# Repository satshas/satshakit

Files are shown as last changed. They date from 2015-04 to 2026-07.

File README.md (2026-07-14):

**IMPORTANT:** this repository is outdated, please find all the new repos about the satshakit boards here: **[satshakit Github organization](https://github.com/satshakit/)**

<h1 style="font-family: courier;" align="center"> satshakit</h1>
<p align="center">
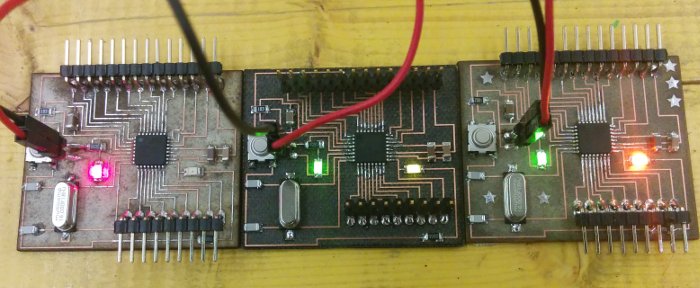
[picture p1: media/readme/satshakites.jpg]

<div align="center"><i>An improved & fabbable 100% Arduino IDE/libraries compatible board.</i></div>
</p>  

The story
--
satshakit born during my **[FabAcademy2015](http://fabacademy.org/archives/2015/eu/students/ingrassia.daniele/index.html)**  as one the first test boards for my quadcopter final project. As some of my fellow students had difficulties with **[Fabkit](http://fabacademy.org/archives/2015/doc/projects/fabkit-0.4.html)**, they tried to make this prototype board. The board was very appreciated that now almost all my fellow students made it for their exercises, or use it as a **starting point for their final projects**. Thus I decided to do this release, if anyone wants to try it. Now, one year later, I am again in a FabLab developing new satshakit boards in my spare time.

What is satshakit?
--

satshakit is a **100% Arduino IDE  and libraries compatible**, fabbable and open source board, and also an improved version of [Fabkit](http://fabacademy.org/archives/2015/doc/projects/fabkit-0.4.html). 

Main **improvements and features** over Fabkit are:

- **16Mhz** instead of 8Mhz
- **crystal** instead of resonator
- **costs less** (7-9 euro vs 13 euro)
- 100% compatible with **default Arduino IDE** (satshakit is recognized as Arduino UNO)
- ADC6/7 connected instead of ADC6/7 not connected (satshakit laser and cnc)
- larger space to easy soldering (satshakit laser and cnc)

satshakit boards
--

There are different kinds of **satshakit boards** depending on the **fabrication technique** you will use to make them, or on the **size** of the board. 

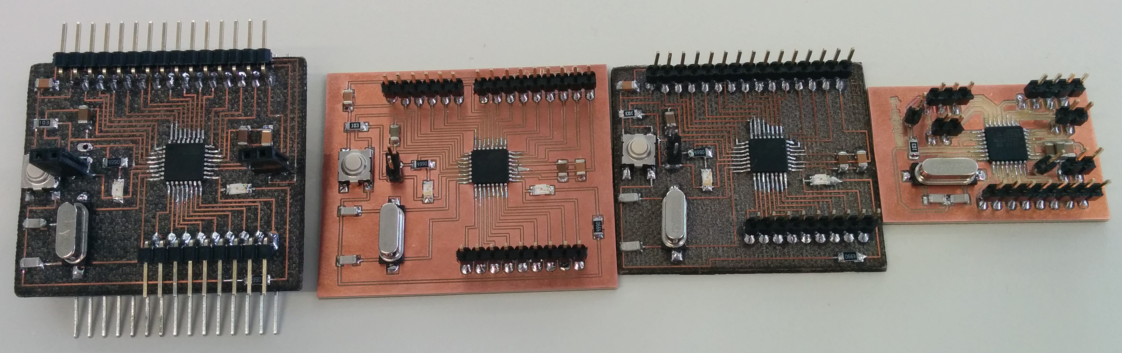
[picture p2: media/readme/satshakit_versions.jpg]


Here is a comparison table about different satshakit boards:

|name|mcu|pins|size(mm)|
| :---: | :---:|:---:|:---:|
|`satshakit laser`|ATmega328P|Arduino + ADC6/7|48 x 42|
|`satshakit cnc`|ATmega328P| Arduino + ADC6/7  |54 x 45|
|`satshakit multicore`|2 x ATmega328P| 2 x Arduino + ADC6/7|50 x 42|
|`satshakit micro`| ATmega328P|Arduino|40 x 24|

satshakit laser and cnc
--

**satshakit laser** and **satshakit cnc** are the standard versions of the satshakit. They are actually the same board, showing some layout differences to improve the fabrication process using a **fiber laser** cutter machine, or a little **cnc mill**. These satshakits are meant to be a general purpose board, having the full Arduino pinout plus ADC6/7 pins, large space for easy soldering and two led onboard for power and pin 13.

Here is the **satshakit laser board**:

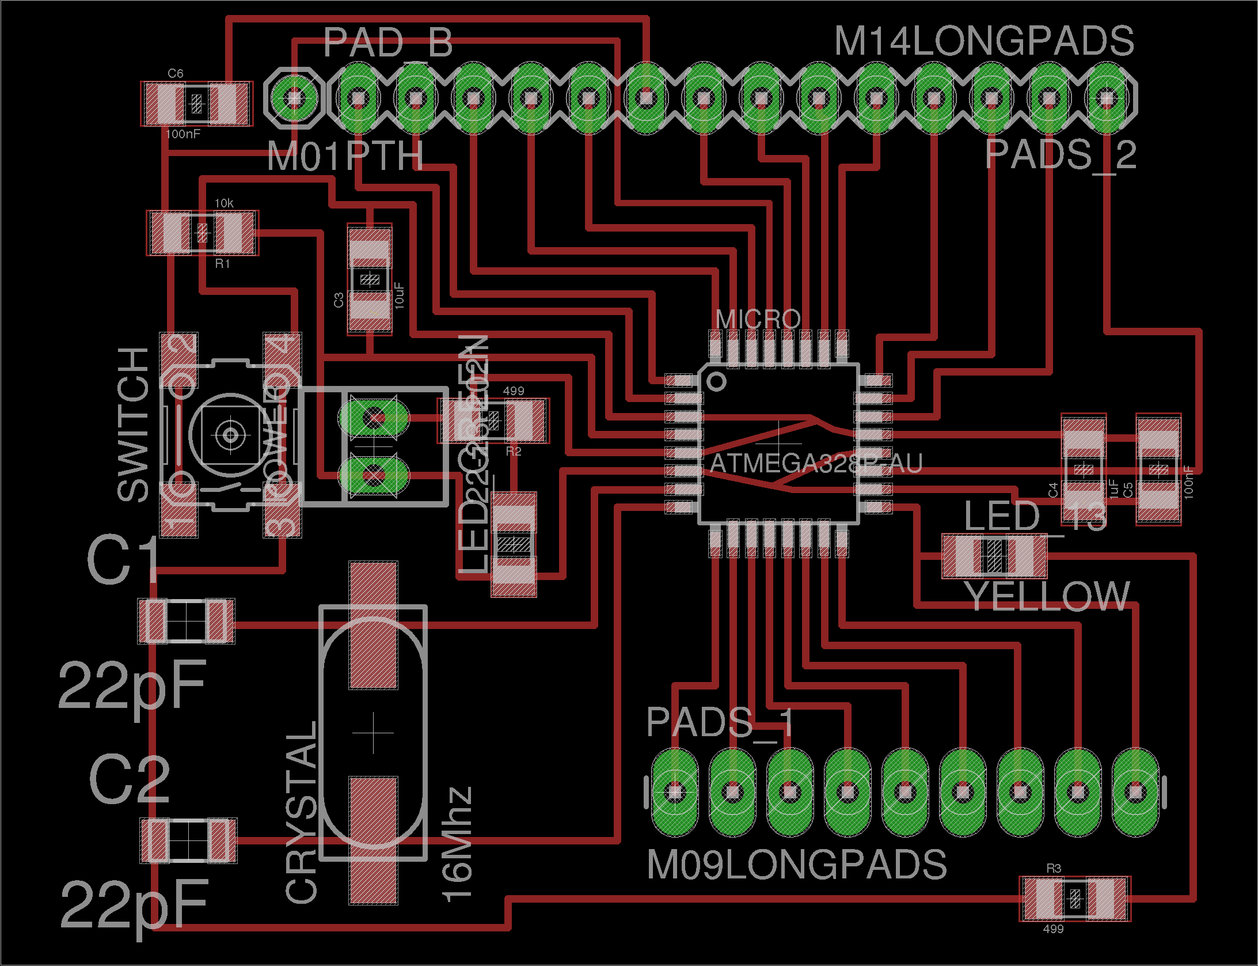
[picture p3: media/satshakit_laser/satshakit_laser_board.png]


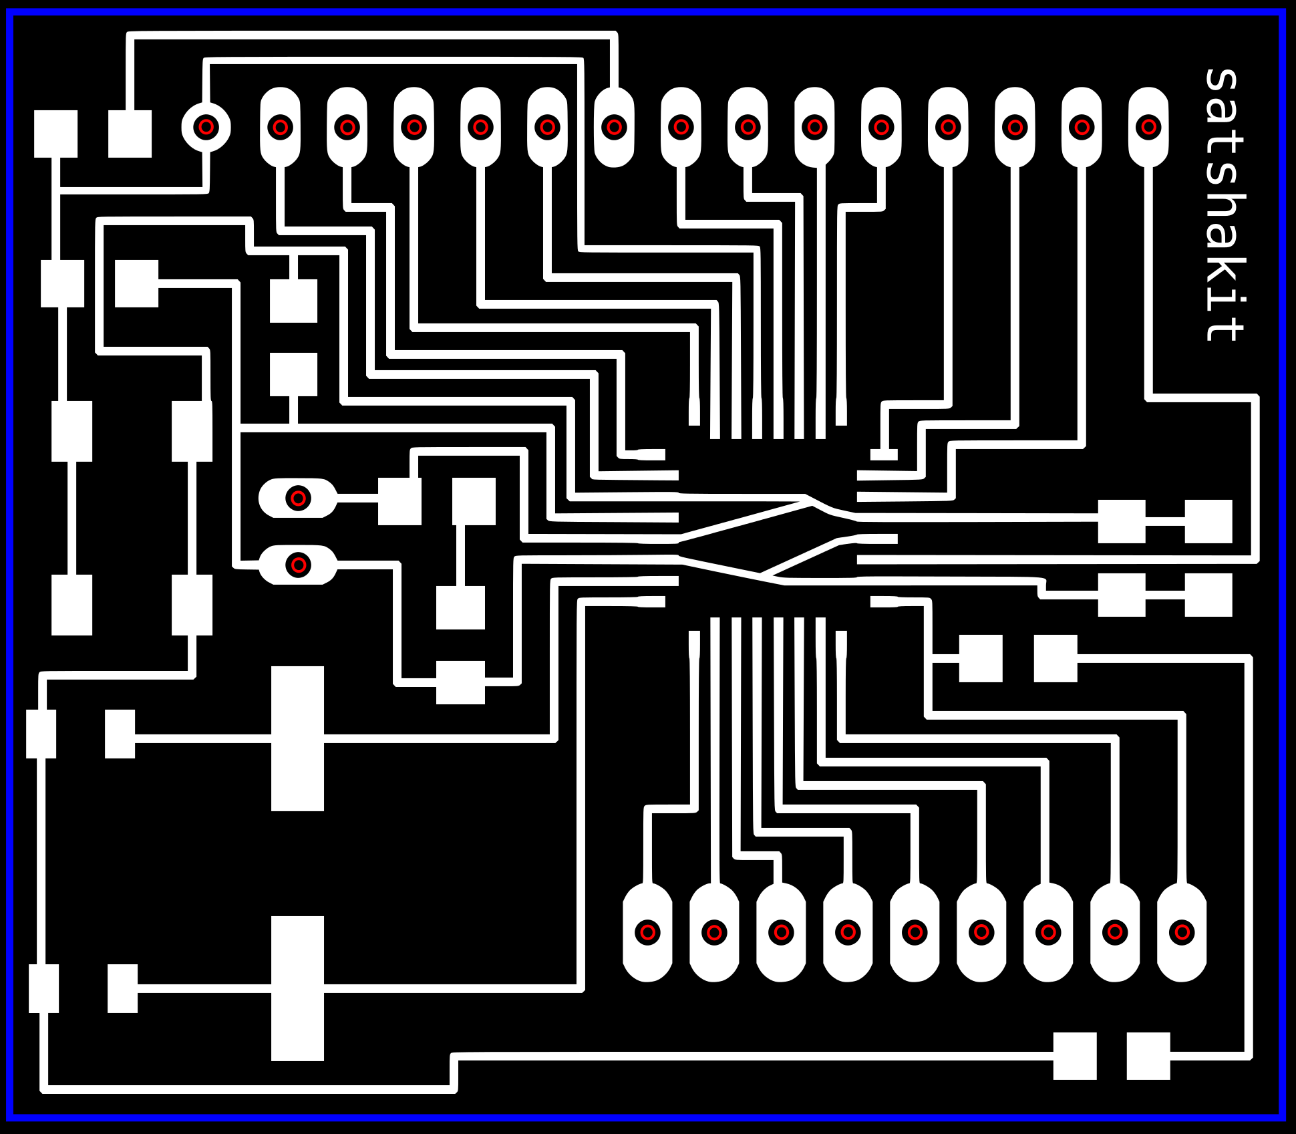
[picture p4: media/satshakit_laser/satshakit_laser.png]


And this is the **satshakit cnc board**:

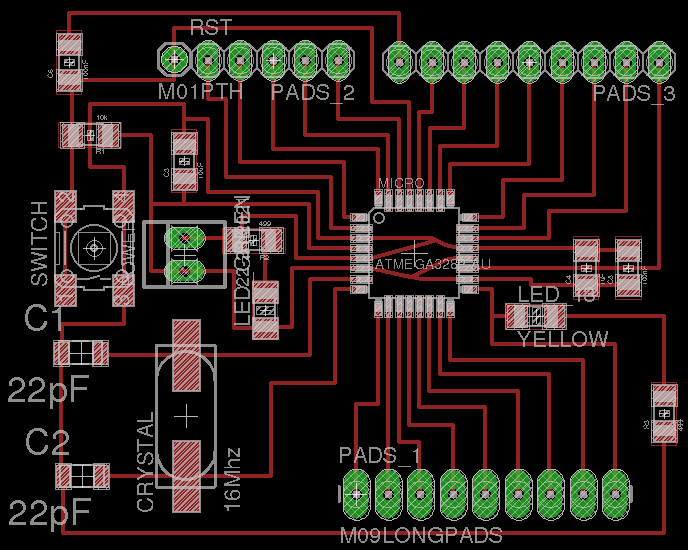
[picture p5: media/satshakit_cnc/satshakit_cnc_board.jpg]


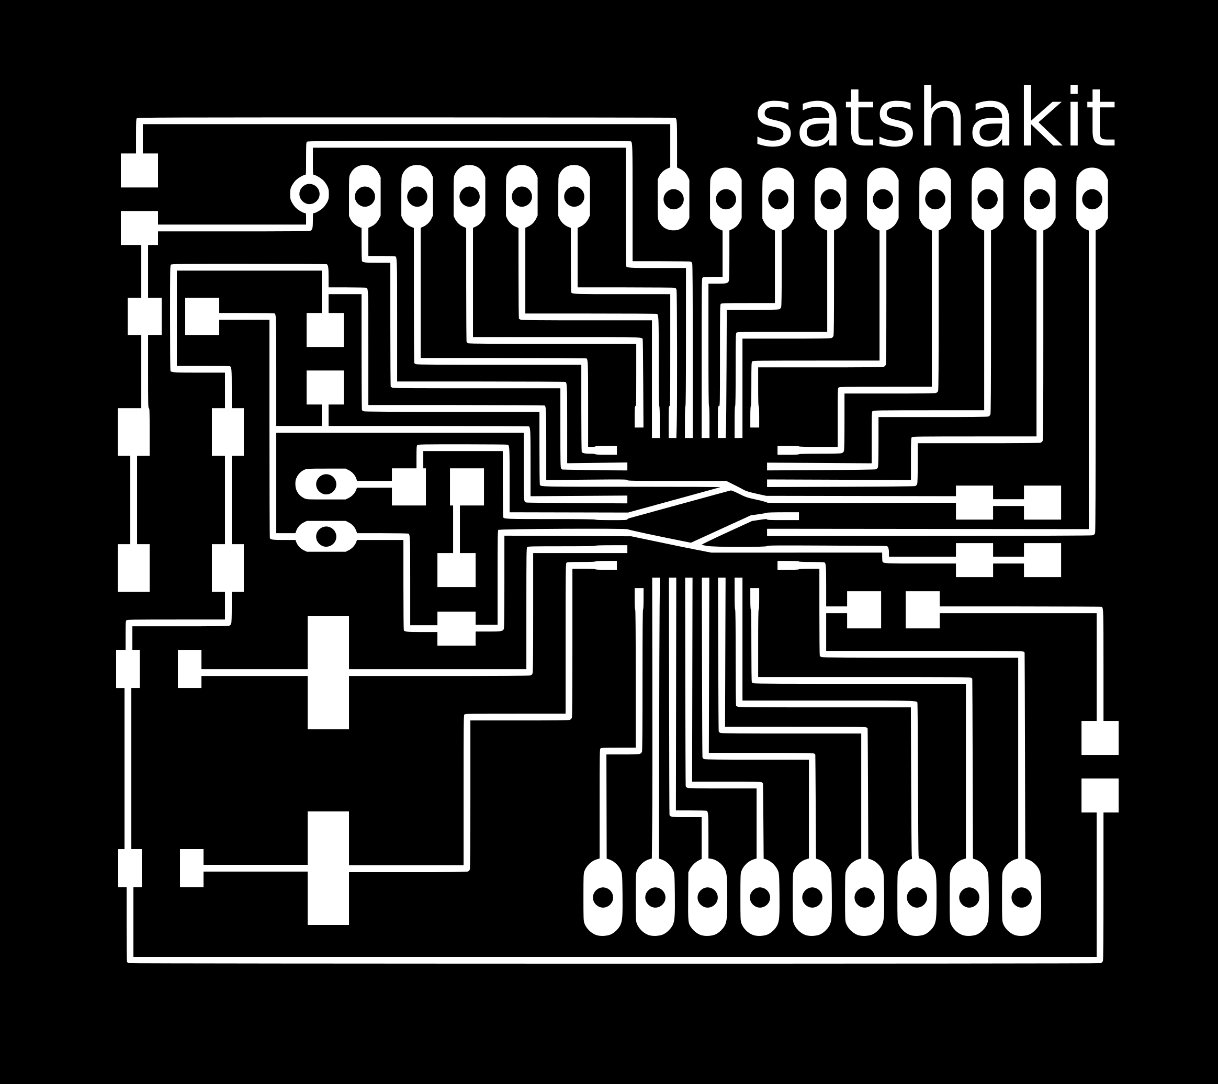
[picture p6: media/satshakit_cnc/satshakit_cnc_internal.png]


**downloads (right click, download as)**

- [satshakit cnc svg](https://raw.githubusercontent.com/satshas/satshakit/master/media/satshakit_cnc/satshakit_cnc.svg)
- [satshakit cnc internal png](https://raw.githubusercontent.com/satshas/satshakit/master/media/satshakit_cnc/satshakit_cnc_internal.png)
- [satshakit cnc holes png](https://raw.githubusercontent.com/satshas/satshakit/master/media/satshakit_cnc/satshakit_cnc_holes.png)
- [satshakit cnc cut png](https://raw.githubusercontent.com/satshas/satshakit/master/media/satshakit_cnc/satshakit_cnc_cut.png)
- [satshakit cnc cut tips png](https://raw.githubusercontent.com/satshas/satshakit/master/media/satshakit_cnc/satshakit_cnc_cut_tip.png)
- [satshakit cnc schematic](https://raw.githubusercontent.com/satshas/satshakit/master/eagle_projects/satshakit_cnc/satshakit_cnc.sch)
- [satshakit cnc board](https://raw.githubusercontent.com/satshas/satshakit/master/eagle_projects/satshakit_cnc/satshakit_cnc.brd)
- [satshakit laser svg](https://raw.githubusercontent.com/satshas/satshakit/master/media/satshakit_laser/satshakit_laser.svg)
- [satshakit laser schematic](https://raw.githubusercontent.com/satshas/satshakit/master/eagle_projects/satshakit_laser/satshakit_laser.sch)
- [satshakit laser board](https://raw.githubusercontent.com/satshas/satshakit/master/eagle_projects/satshakit_laser/satshakit_laser.brd)
- [satshakit laser and cnc BOM Open Document](https://github.com/satshas/satshakit/raw/master/docs/satshakit_others/satshakit_BOM.ods)
- [satshakit laser and cnc BOM Excel](https://github.com/satshas/satshakit/raw/master/docs/satshakit_others/satshakit_BOM.xlsx)

**media**

satshakit laser:

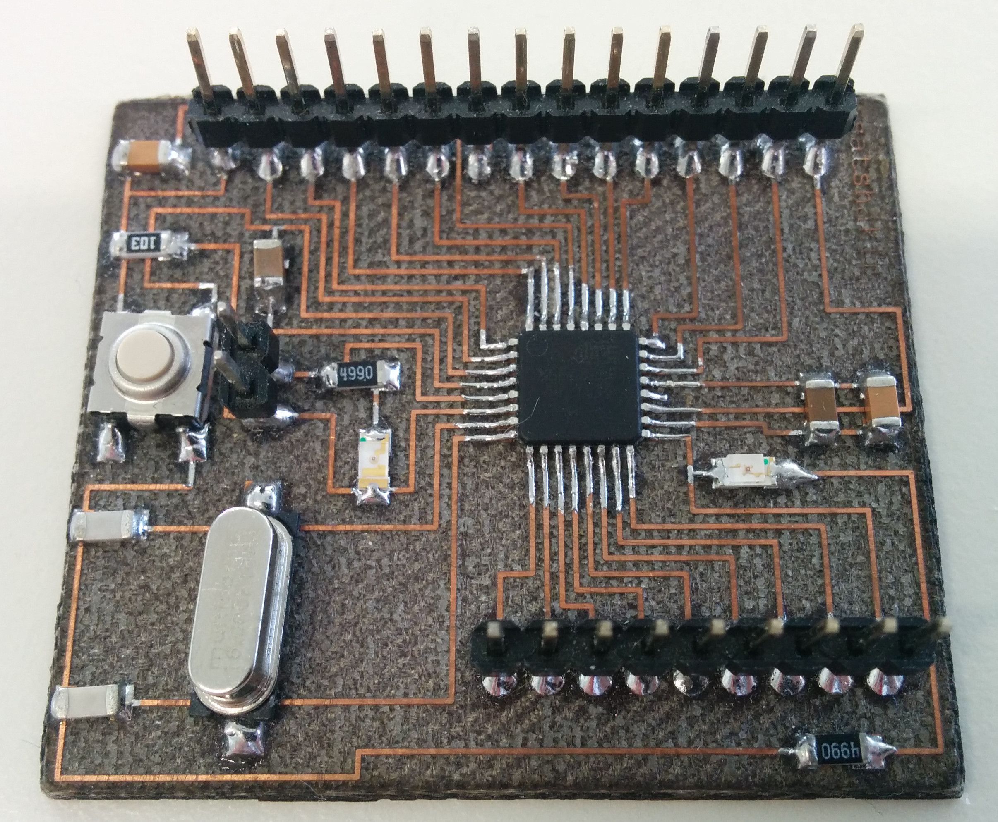
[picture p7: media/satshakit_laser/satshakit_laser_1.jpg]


satshakit cnc:

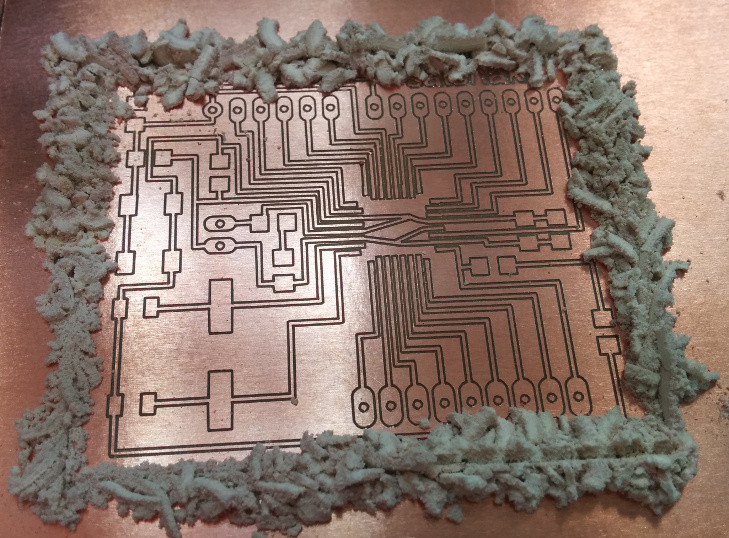
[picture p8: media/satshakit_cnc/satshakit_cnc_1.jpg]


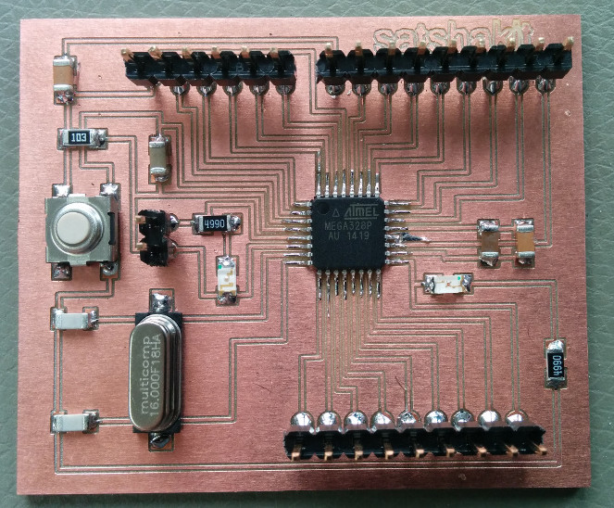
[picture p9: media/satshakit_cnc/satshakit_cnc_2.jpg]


satshakit cnc blinks:

<a href="http://www.youtube.com/watch?feature=player_embedded&v=38LhM9Qynuc
" target="_blank"></a>

satshakit programmed with a FabISP:

<a href="http://www.youtube.com/watch?feature=player_embedded&v=YNITEv0ebkc
" target="_blank"></a>

Here are some videos of satshakit while is working with **different configuration and/or sensors**:

<a href="http://www.youtube.com/watch?feature=player_embedded&v=Gk_RFebLofY
" target="_blank"></a>

<a href="http://www.youtube.com/watch?feature=player_embedded&v=ZQmN3uTlZuc
" target="_blank"></a>

<a href="http://www.youtube.com/watch?feature=player_embedded&v=kZMLoyP47z4
" target="_blank"></a>

<a href="http://www.youtube.com/watch?feature=player_embedded&v=9XcrL3Ypu_s
" target="_blank"></a>

<a href="http://www.youtube.com/watch?feature=player_embedded&v=zIuTUFps1bE
" target="_blank"></a>

satshakit car with sonars sensors and Raspberry Pi:

<a href="http://www.youtube.com/watch?feature=player_embedded&v=A0I6Nj6D2sE
" target="_blank"></a>

satshakit little radar, a **satshakit modified board** with an ULN2003A:

<a href="http://www.youtube.com/watch?feature=player_embedded&v=0FD7bHNqlxU
" target="_blank"></a>

satshakit micro
--

**satshakit micro** is a downsized version of the satshakit laser and cnc, developed to be used in **constrained space applications** like embedding the board in textiles or in small objects, or useful for who wants just a **bare metal board** to start with, also easy to be modified and/or customized. While satshakit micro is less than half the size of the other satshakits, it's a **full featured board** with the full Adruino pinout, missing only the possibility to be programmed using an FTDI cable.

Here is the **satshakit micro board**:

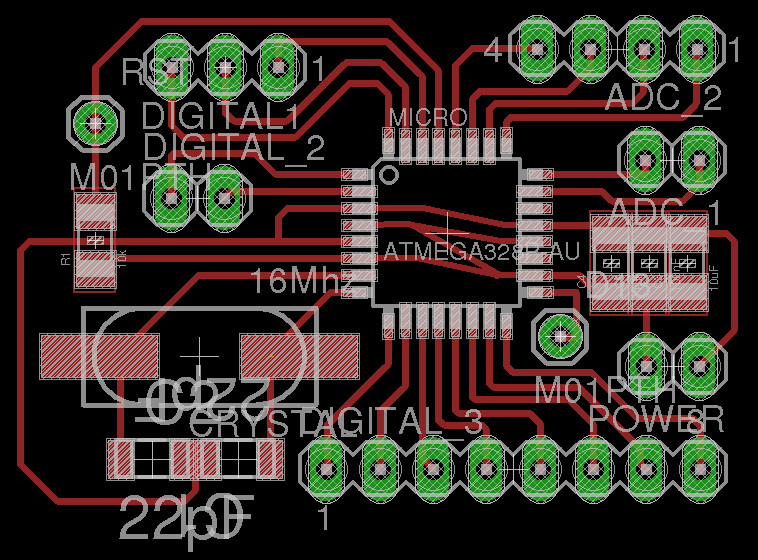
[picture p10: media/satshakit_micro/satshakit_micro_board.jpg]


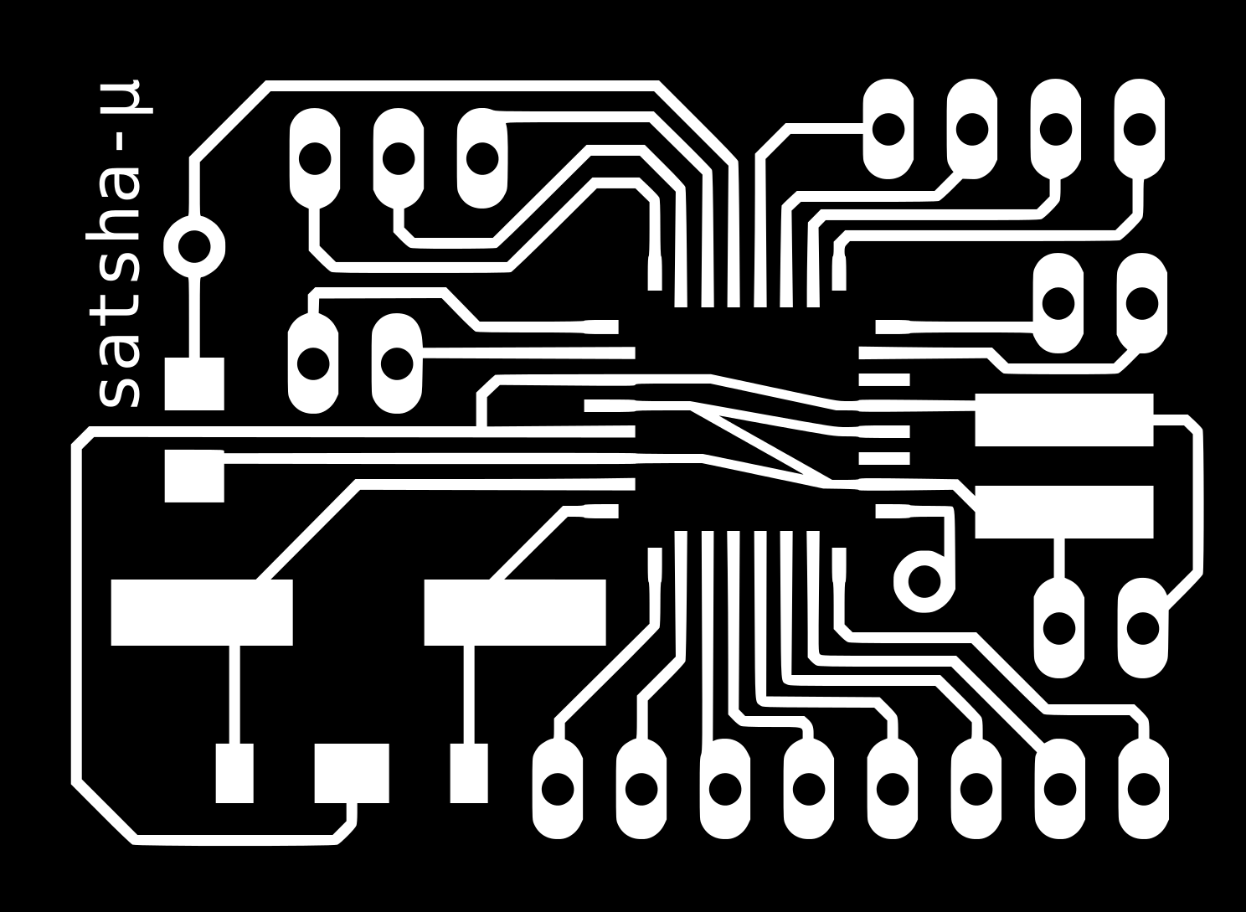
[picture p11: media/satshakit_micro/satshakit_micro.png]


**downloads (right click, download as)**

- [satshakit micro svg](https://raw.githubusercontent.com/satshas/satshakit/master/media/satshakit_micro/satshakit_micro.svg)
- [satshakit micro internal png](https://raw.githubusercontent.com/satshas/satshakit/master/media/satshakit_micro/satshakit_micro_internal.png)
- [satshakit micro holes png](https://raw.githubusercontent.com/satshas/satshakit/master/media/satshakit_micro/satshakit_micro_holes.png)
- [satshakit micro cut png](https://raw.githubusercontent.com/satshas/satshakit/master/media/satshakit_micro/satshakit_micro_cut.png)
- [satshakit micro cut tips png](https://raw.githubusercontent.com/satshas/satshakit/master/media/satshakit_micro/satshakit_micro_cut_tips.png)
- [satshakit micro schematic](https://raw.githubusercontent.com/satshas/satshakit/master/eagle_projects/satshakit_micro/satshakit_micro.sch)
- [satshakit micro board](https://raw.githubusercontent.com/satshas/satshakit/master/eagle_projects/satshakit_micro/satshakit_micro.brd)
- [satshakit micro BOM Open Document](https://github.com/satshas/satshakit/raw/master/docs/satshakit_micro/satshakit_micro_BOM.ods)
- [satshakit micro BOM Excel](https://github.com/satshas/satshakit/raw/master/docs/satshakit_micro/satshakit_micro_BOM.xlsx)

**media**

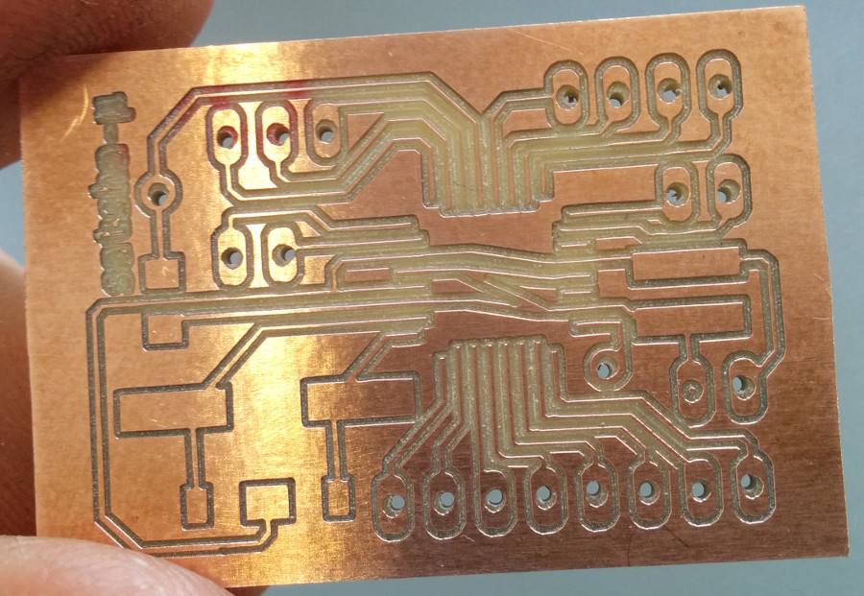
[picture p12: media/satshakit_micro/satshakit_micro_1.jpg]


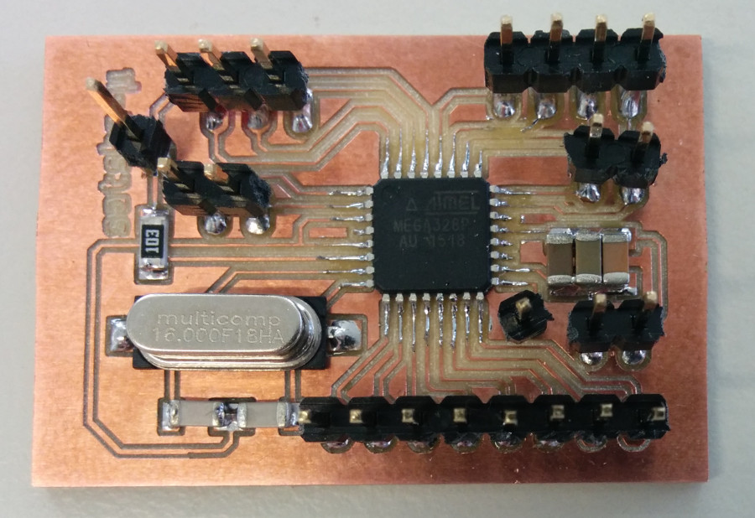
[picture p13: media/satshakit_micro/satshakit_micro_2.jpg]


satshakit micro blink:

<a href="http://www.youtube.com/watch?feature=player_embedded&v=3qz0hKS8dOc
" target="_blank"></a>

satshakit multicore
--

**satshakit multicore** boards born as a further experiment on **MCU multithreading and networking**. satshakit multicore boards have only the following modifications in confront of the standard satshakit: 4 extra pin headers (1 GND,1 VCC,1 A4, 1 A5). These pin headers serve also a structural pillars to build a modular satshakit tower. So modular satshakit share the same power source, and can direct communicate with **I2C**. 

Here is the **satshakit multicore board**:

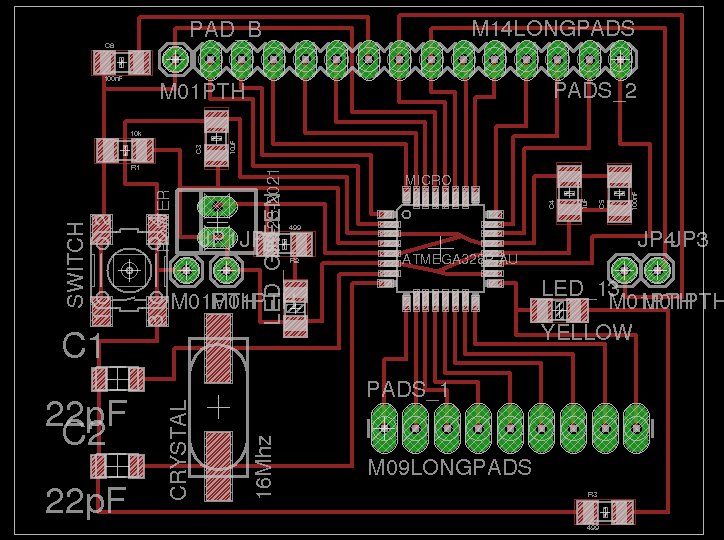
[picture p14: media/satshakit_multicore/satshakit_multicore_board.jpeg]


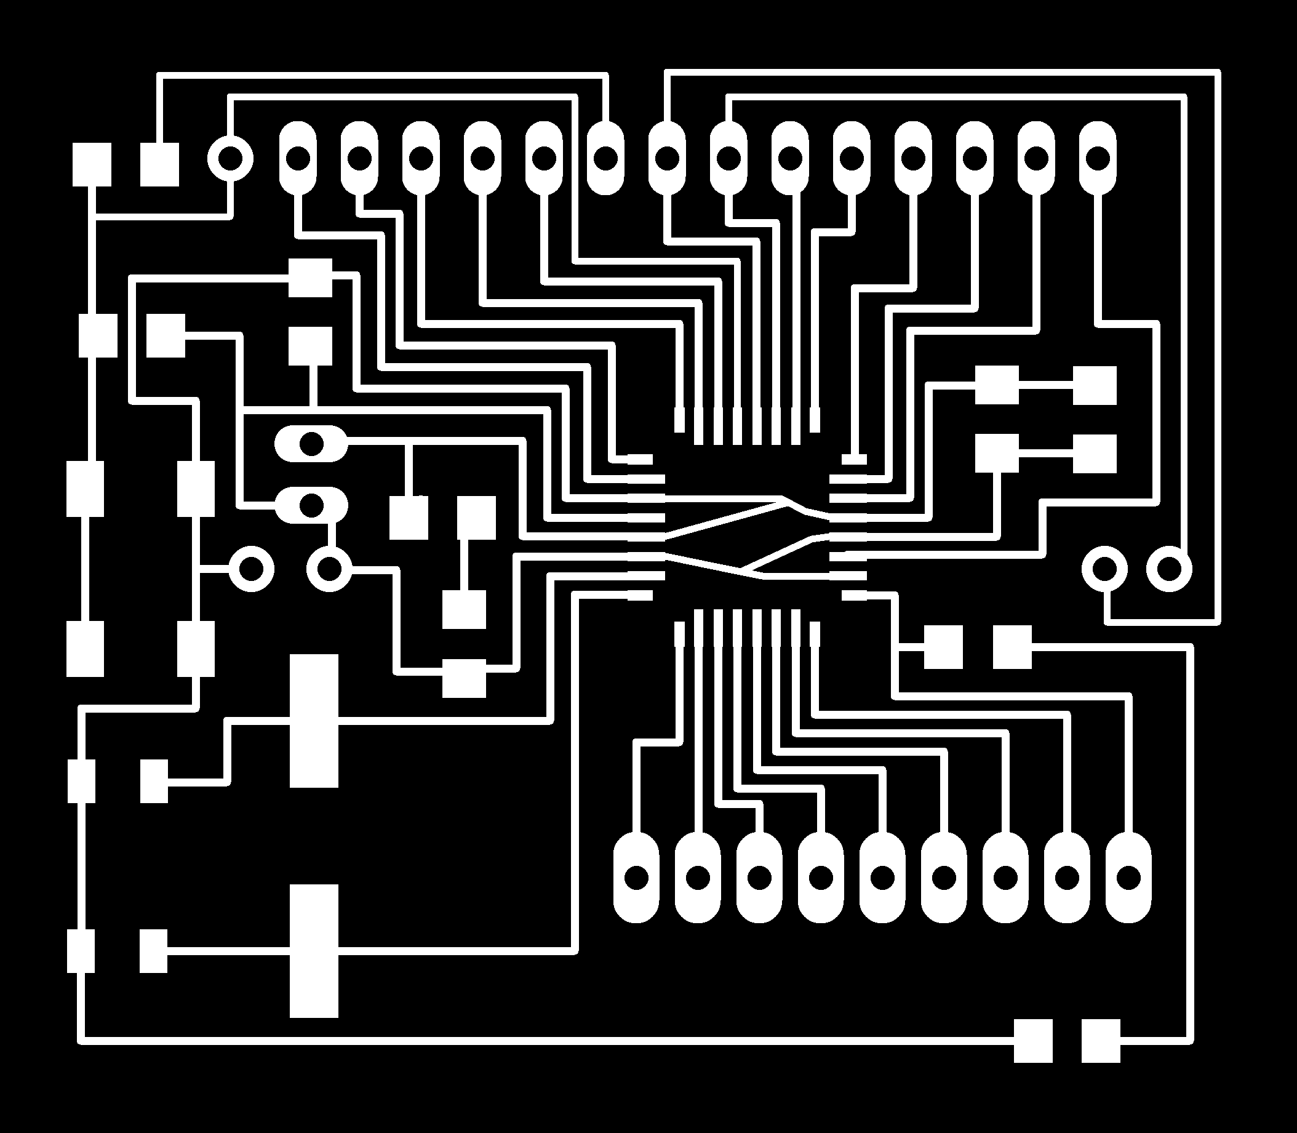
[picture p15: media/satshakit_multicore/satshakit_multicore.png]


**downloads (right click, download as)**

- [satshakit multicore svg](https://raw.githubusercontent.com/satshas/satshakit/master/media/satshakit_multicore/satshakit_multicore.svg)
- [satshakit multicore schematic](https://raw.githubusercontent.com/satshas/satshakit/master/eagle_projects/satshakit_multicore/satshakit_multicore.sch)
- [satshakit multicore board](https://raw.githubusercontent.com/satshas/satshakit/master/eagle_projects/satshakit_multicore/satshakit_multicore.brd)
- [satshakit multicore BOM Open Document](https://github.com/satshas/satshakit/raw/master/docs/satshakit_others/satshakit_BOM.ods)
- [satshakit multicore BOM Excel](https://github.com/satshas/satshakit/raw/master/docs/satshakit_others/satshakit_BOM.xlsx)

**media**

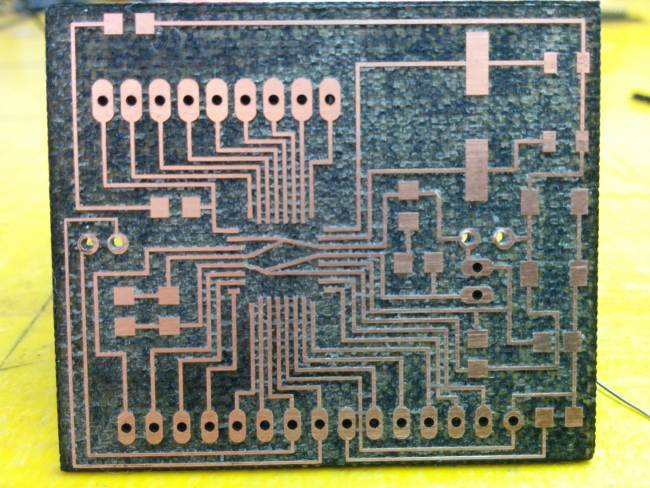
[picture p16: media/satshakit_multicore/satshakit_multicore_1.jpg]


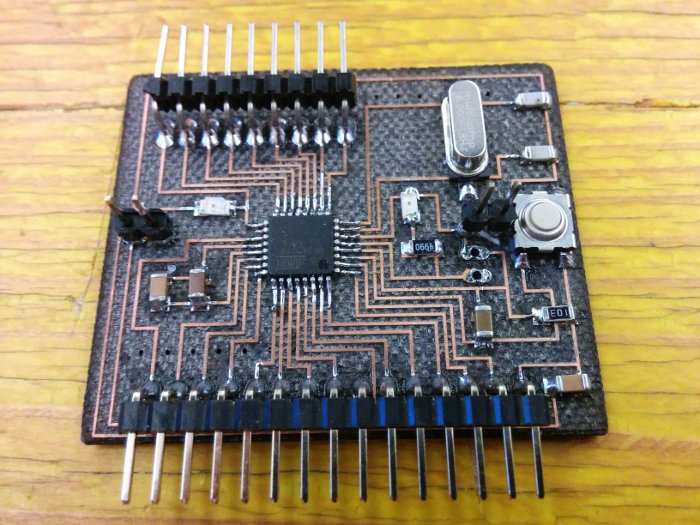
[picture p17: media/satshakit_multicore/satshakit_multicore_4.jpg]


5-core satshakit system:

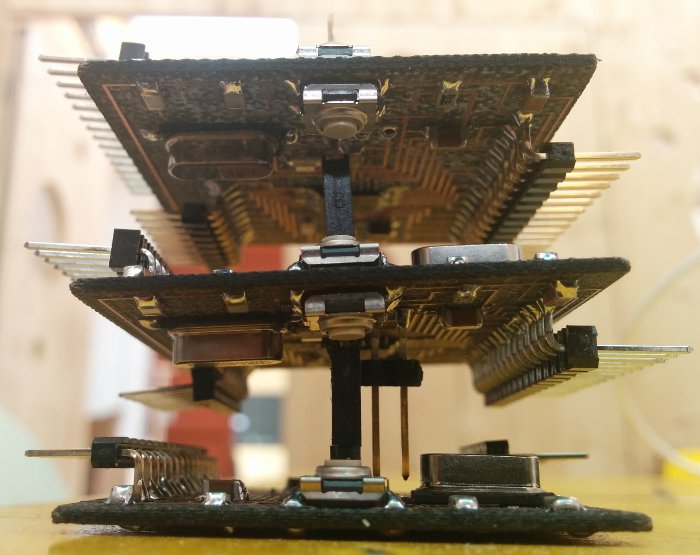
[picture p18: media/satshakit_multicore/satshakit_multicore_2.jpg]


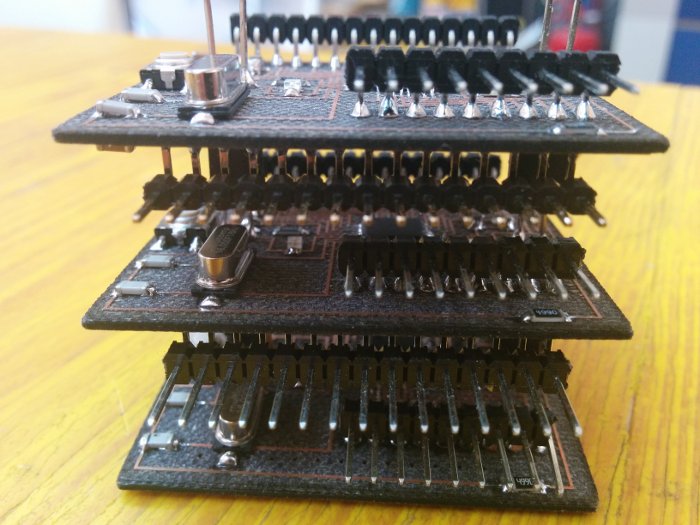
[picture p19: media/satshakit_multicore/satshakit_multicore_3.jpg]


satshakit multicore assembly & test:

<a href="http://www.youtube.com/watch?feature=player_embedded&v=nVHYBydPKpk
" target="_blank"></a>

satshakit multicore blink:

<a href="http://www.youtube.com/watch?feature=player_embedded&v=bxnmX-B9Czo
" target="_blank"></a>

quad satshakit bluetooth triangulation:

<a href="http://www.youtube.com/watch?feature=player_embedded&v=uuVuoD9TB4M
" target="_blank"></a>

satshakit power board
--

Due to the power requirements of a multicore satshakit system and to eventually provide power to **3.3V devices**, I have also developed a simple power board. This power board can work with 7V-12V as input voltage, and give out 5V and 3.3V. I made this power board with the components I had available, obviously you can make this board only with SMD components.

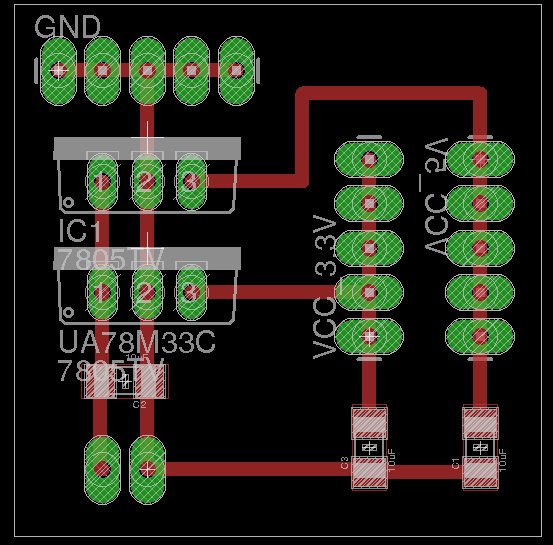
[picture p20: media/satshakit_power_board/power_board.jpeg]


**downloads (right click, download as)**

- [satshakit power board schematic](https://raw.githubusercontent.com/satshas/satshakit/master/eagle_projects/satshakit_power_board/satshakit_power_board.sch)
- [satshakit power board board](https://raw.githubusercontent.com/satshas/satshakit/master/eagle_projects/satshakit_power_board/satshakit_power_board.brd)

Here is a picture of a soldered power board:

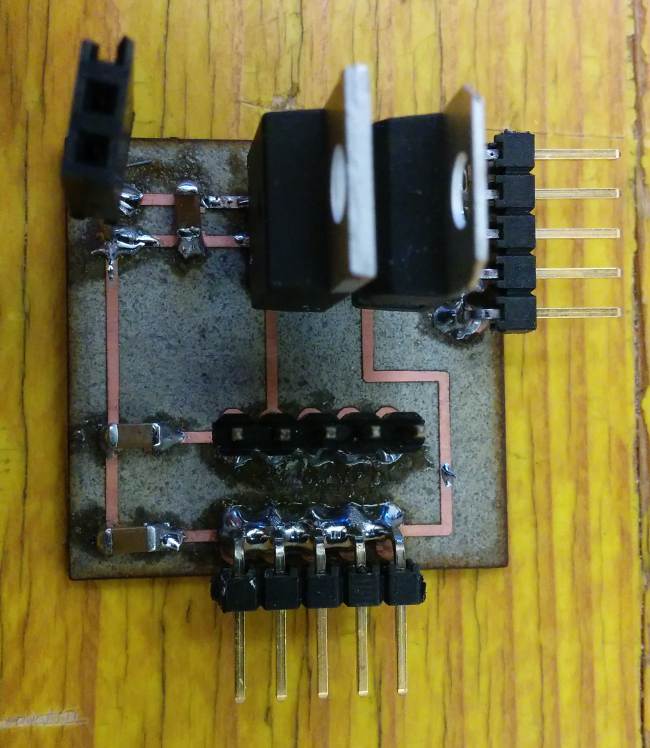
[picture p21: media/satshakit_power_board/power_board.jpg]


Getting Started
--
A satshakit board is **totally like an Arduino board**, thus is possible to use the Arduino IDE without any modification. When you finish solder satshakit, you're ready to program it. If you want to use satshakit as an Arduino, you first need to **upload Arduino bootloader**. This will also set the ATmega328P fuses as the same of an Arduino UNO.
 To do this you need to use a **programmer**, for example another Arduino or FabISP. If you plan to program a satshakit with an Arduino, be sure to upload the **Arduino as ISP skecth** before connecting the satshakit to it.

Here are the connection schemas to program **satshakit laser**, **satshakit cnc** or a **satshakit multicore** with an Arduino as ISP or with a FabISP:

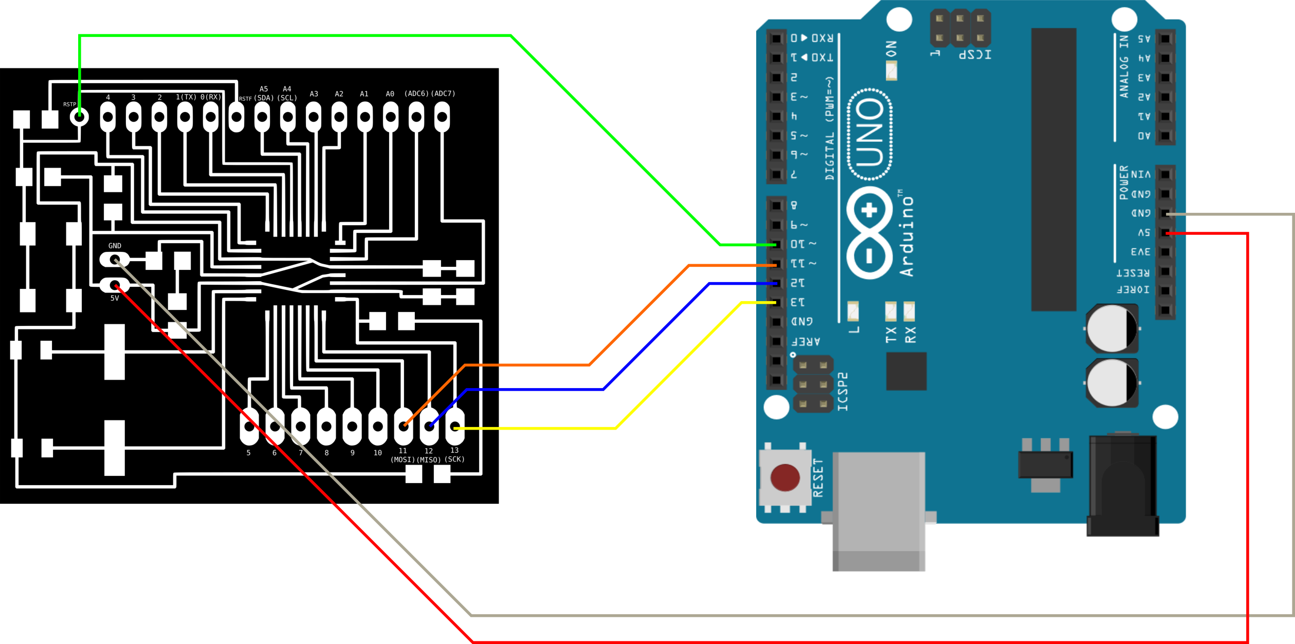
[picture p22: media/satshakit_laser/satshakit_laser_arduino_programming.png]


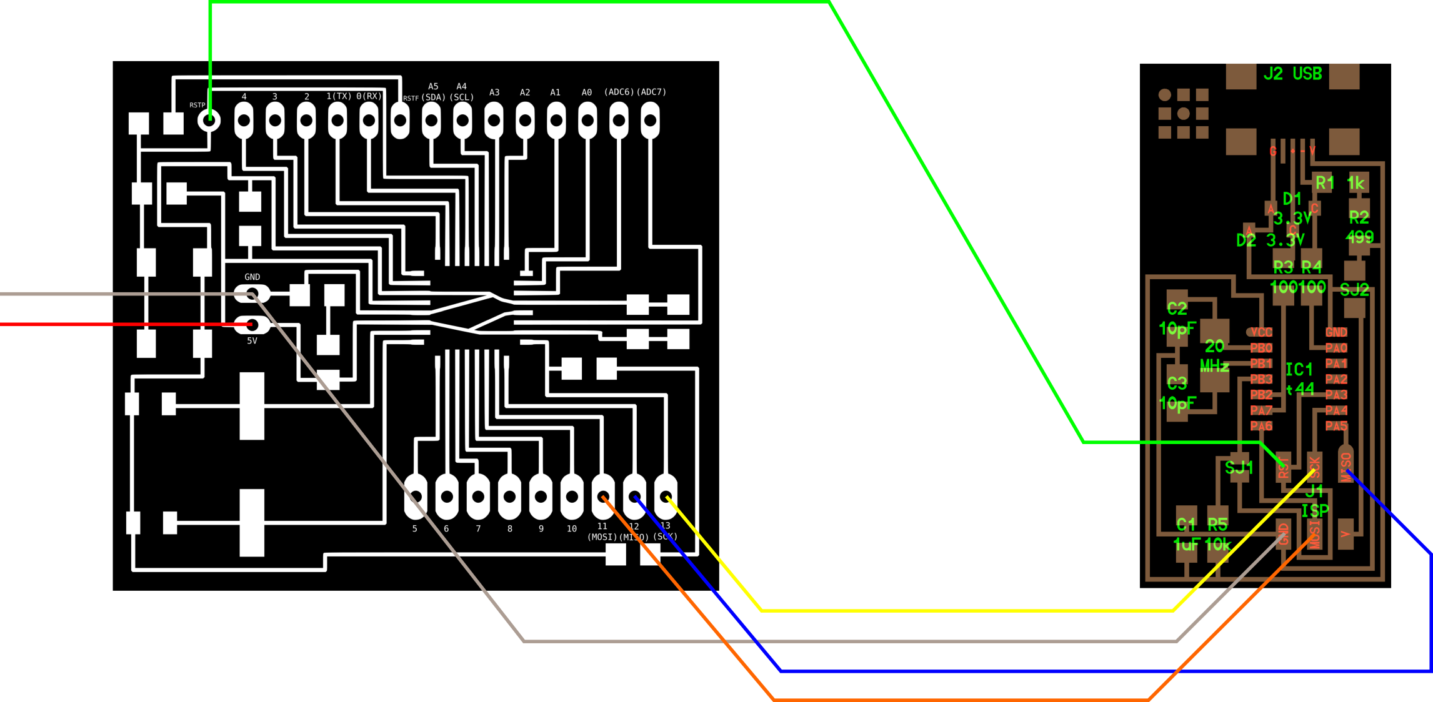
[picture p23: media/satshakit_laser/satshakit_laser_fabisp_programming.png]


If you made a **satshakit micro**, here are the connection schemas to program it as before for the other satshakits:

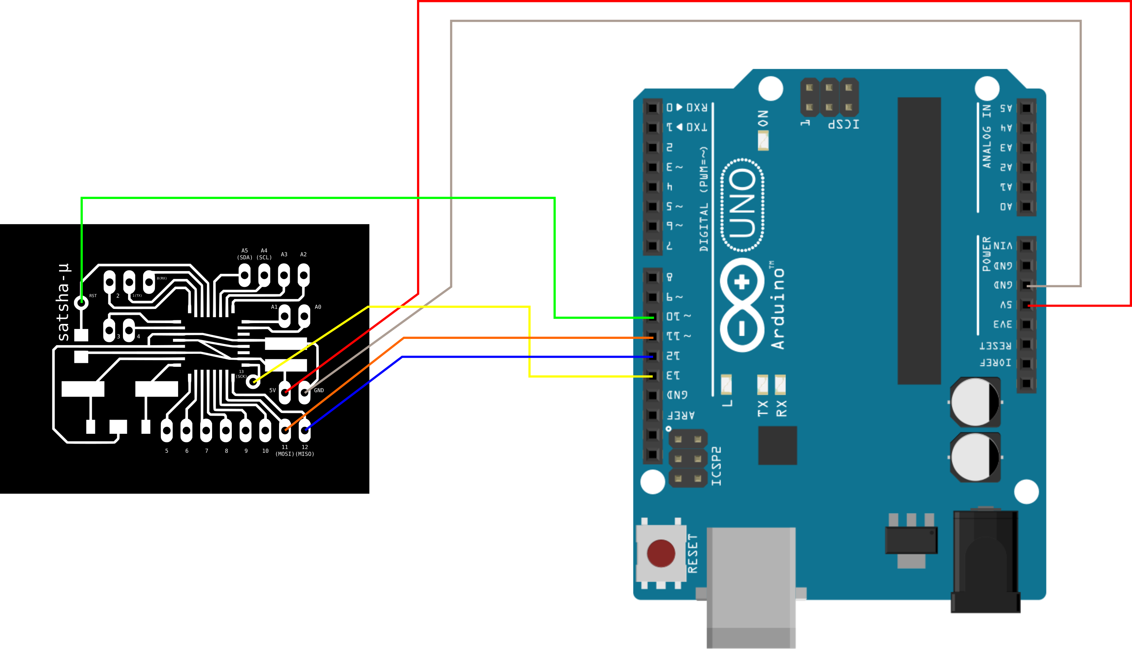
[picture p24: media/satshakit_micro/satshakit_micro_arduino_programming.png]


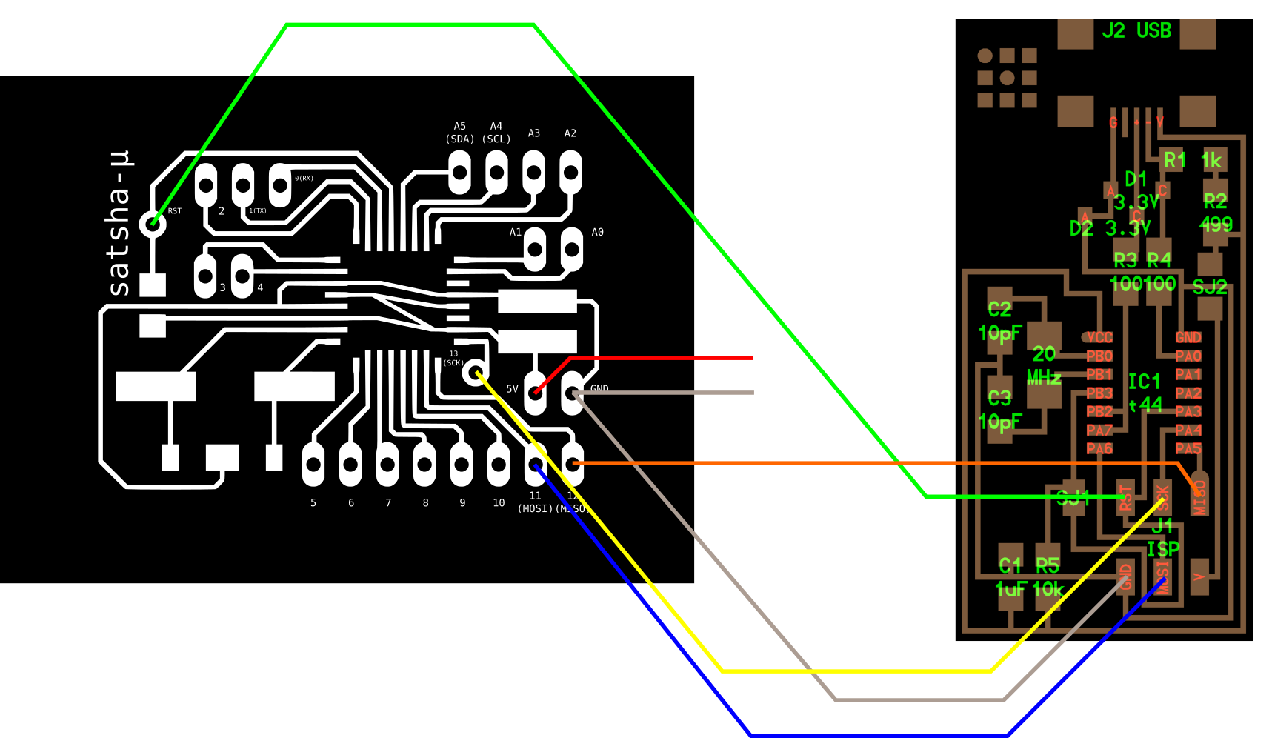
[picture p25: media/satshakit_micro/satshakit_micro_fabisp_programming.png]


Once everything is connected, follow these steps to upload Arduino bootloader:

1. open Arduino IDE 
2. select proper programmer (for example Arduino as ISP or USBtinyISP) 
3. select Arduino UNO as board
4. click on tools->Burn Bootloader

If you made a satshakit cnc, satshakit laser or satshakit multicore, you can use an **FTDI USB cable to upload and use you favourite sketch** without the need to use a programmer anymore. If you made a satshakit micro, you have always to use a programmer, and use the **Sketch >Upload using a programmer** function of the Arduino IDE.

Here is the connection schema to program a satshakit using the FTDI cable:

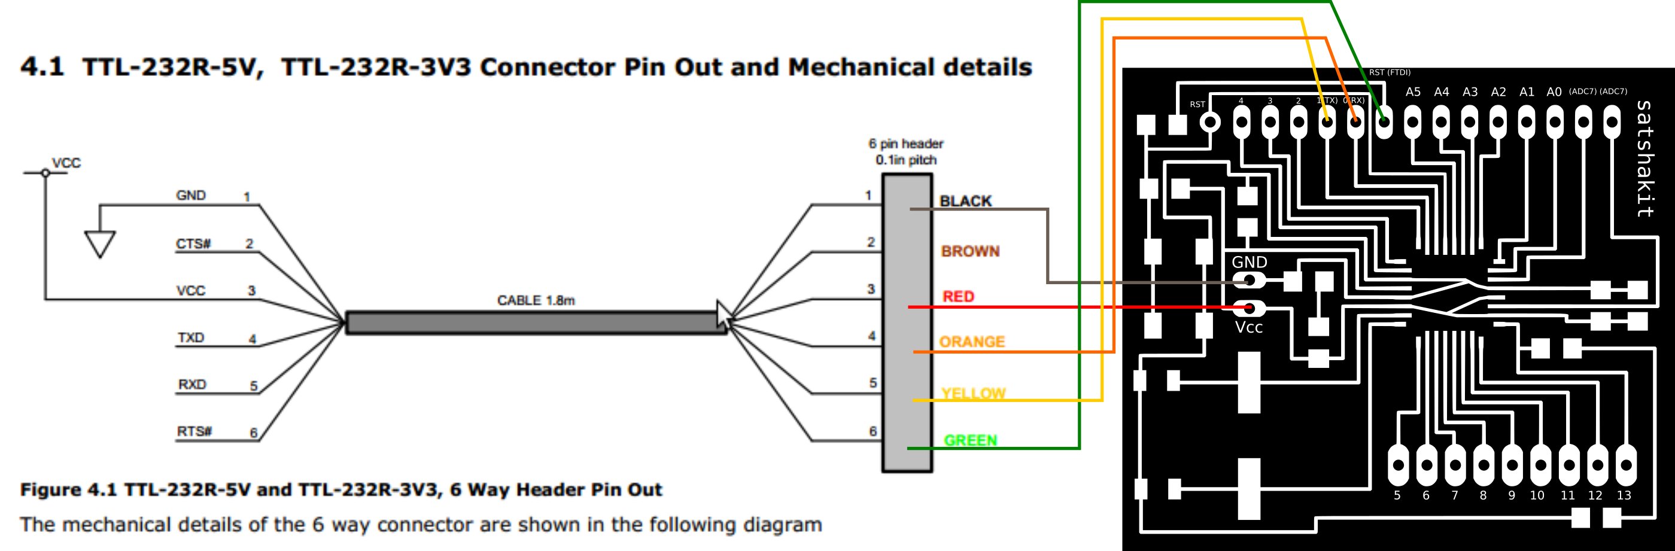
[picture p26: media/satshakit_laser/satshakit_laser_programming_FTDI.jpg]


Remember that if you don't have an FTDI cable you always need a programmer, and to select **File->Upload using a programmer** to upload the code to satshakit.

To use a satshakit like an Arduino, here is the Arduino pinout on satshakit cnc, satshakit laser and satshakit multicore:

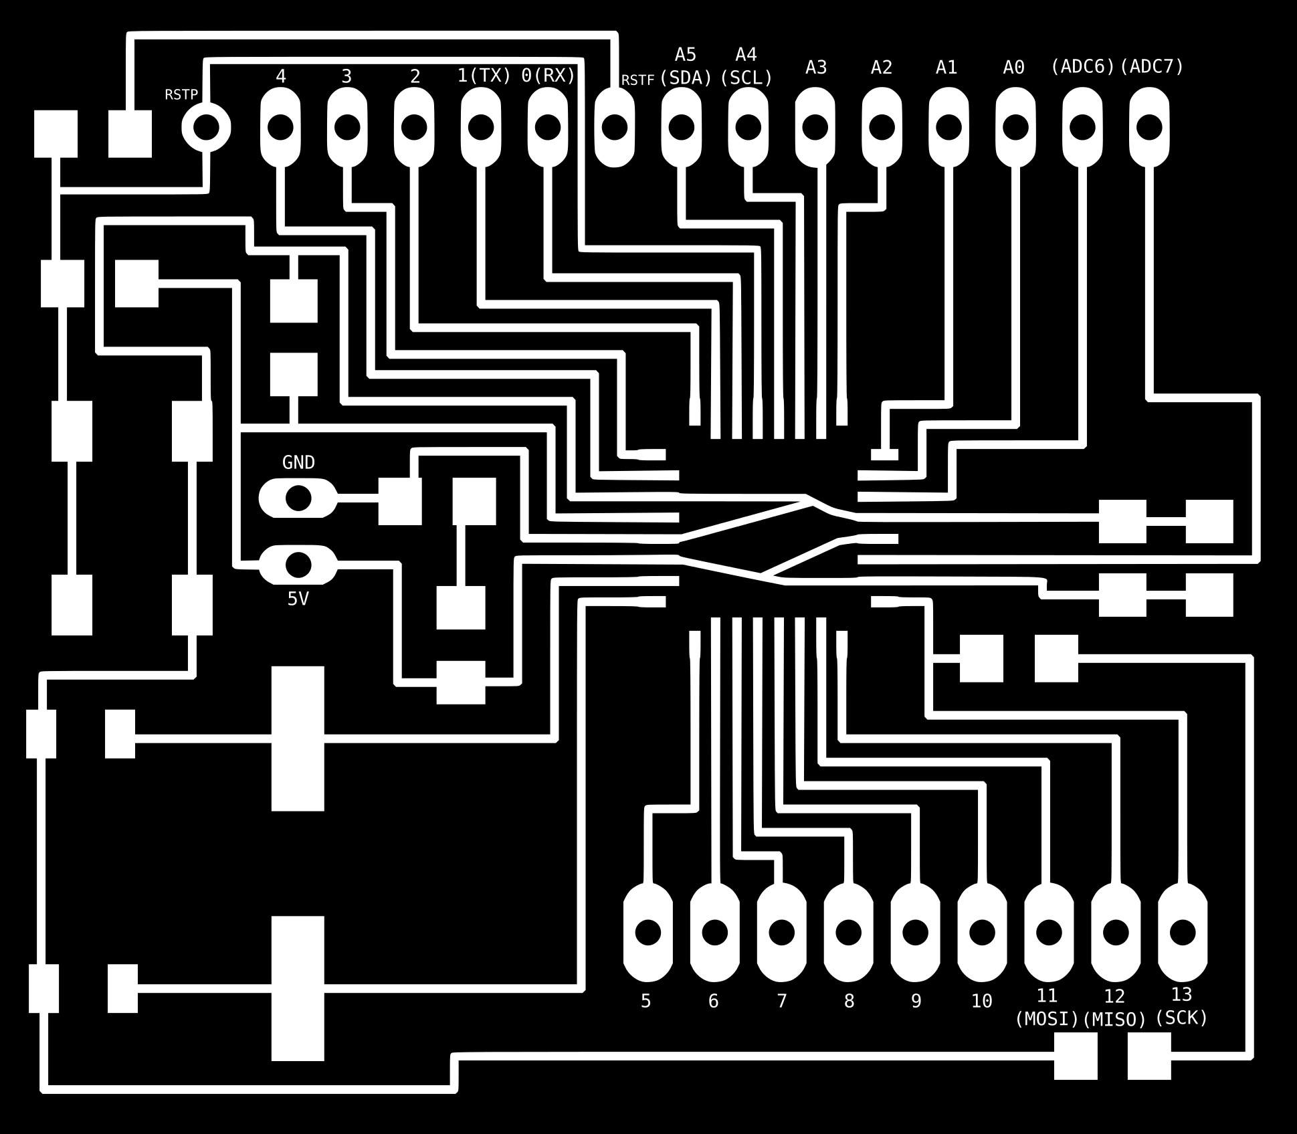
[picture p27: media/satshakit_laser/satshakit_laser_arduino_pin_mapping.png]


And here is the Arduino pinout of the satshakit micro:

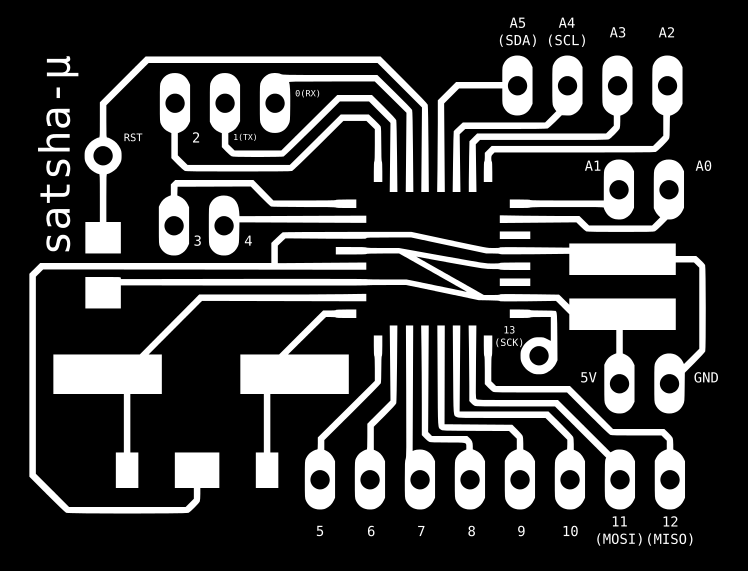
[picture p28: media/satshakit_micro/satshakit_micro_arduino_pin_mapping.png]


What's in the repo
--
- **[docs](https://github.com/satshas/satshakit/tree/master/docs)**: BOM files for Farnell
- **[egle projects](https://github.com/satshas/satshakit/tree/master/eagle_projects)**: eagle projects of satshakit
- **[media](https://github.com/satshas/satshakit/tree/master/media)**: svg of satshakits, connections schemas, images for cnc milling machine and fiber laser cutter, other images

Authors
--

**satshakit cnc and micro:**
- Daniele Ingrassia

**satshakit laser, multicore and power board:**

- Daniele Ingrassia and [Engineering Ingegneria Informatica](http://www.eng.it)

Contact
--
- **ingrassiada@gmail.com**
- **[linkedin](http://it.linkedin.com/in/danieleingrassia)**

Thanks
--
[Fablab opendot](http://www.opendotlab.it/)<br />
info@opendotlab.it<br />
Via Tertulliano N70, 20137, Milan, Italy<br />
 +39.02.36519890<br />

[Fablab Kamp-Lintfort](http://fablab.hochschule-rhein-waal.de/index.php/de/)<br />
Hochschule Rhein-Waal<br />
Friedrich-Heinrich-Allee 25, 47475 Kamp-Lintfort, Germany<br />
fablab@hochschule-rhein-waal.de

License
--
This work is licensed under the terms of Attribution-ShareAlike 4.0 International ([CC BY-NC-SA 4.0](https://creativecommons.org/licenses/by-sa/4.0/)).

Disclaimer  
--

<div class="align-justify">
This hardware/software is provided "as is", and you use the hardware/software at your own risk. Under no circumstances shall any author be liable for direct, indirect, special, incidental, or consequential damages resulting from the use, misuse, or inability to use this hardware/software, even if the authors have been advised of the possibility of such damages.</div>

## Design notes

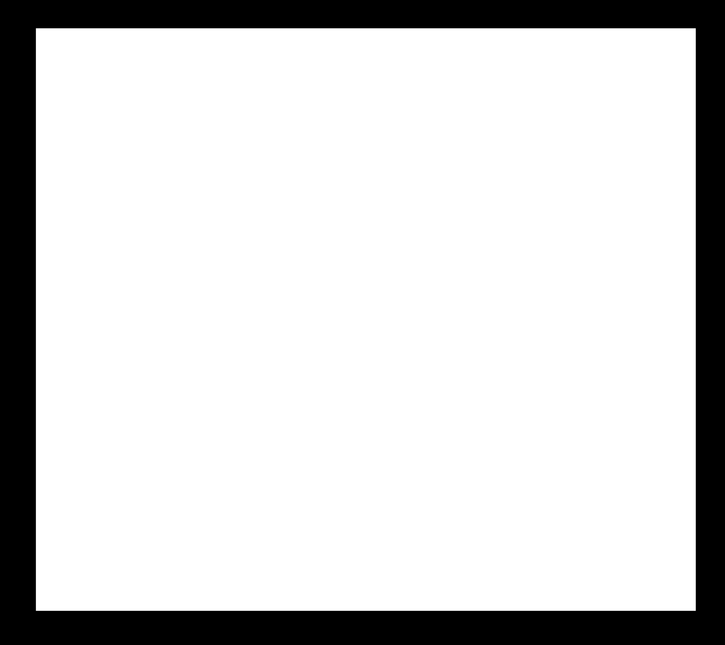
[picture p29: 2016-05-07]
media/satshakit_cnc/satshakit_cnc_cut.png

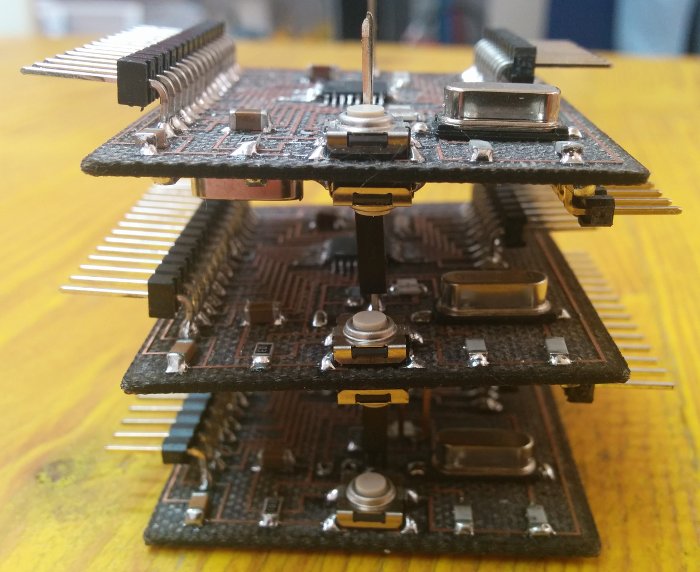
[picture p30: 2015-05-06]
media/satshakit_multicore/satshakit_multicore_5.jpg

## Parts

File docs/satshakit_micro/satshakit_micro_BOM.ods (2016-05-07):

Value | Manufacturer Part No | Package | Description | FARNELL | Price € | Quantity | Min. Quantity Cost €
- | ATMEGA328P-AU | TQFP-32 | microcontroller | 1715486 (http://it.farnell.com/atmel/atmega328p-au/mcu-8bit-atmega-20mhz-tqfp-32/dp/1715486) | 2.78 | 1 | 2.78
16Mhz/18pF | MCRSD16000F183000RR | SMD 11.4 x 4.7 mm | crystal | 2395958 (http://it.farnell.com/multicomp/mcrsd16000f183000rr/crystal-16mhz-18pf-hc49-us-smd/dp/2395958) | 0.20 | 1 | 0.20
10K | ERJ8GEYJ103V | 1206 | resistor | 2057856 (http://it.farnell.com/panasonic-electronic-components/erj8geyj103v/resistore-1206-10k-5-0-25w/dp/2057856) | 0.03 | 1 | 0.26
22pF | MC1206N220J500CT | 1206 | capacitor | 2320891 (http://it.farnell.com/multicomp/mc1206n220j500ct/condens-mlcc-c0g-np0-22pf-50v/dp/2320891) | 0.05 | 2 | 0.47
10uF | MC1206X106K250CT | 1206 | capacitor | 2112753 (http://it.farnell.com/multicomp/mc1206x106k250ct/condensatore-mlcc-x5r-10uf-25v/dp/2112753) | 0.15 | 1 | 0.15
1uF | MC1206F105Z500CT | 1206 | capacitor | 1759455 (http://it.farnell.com/multicomp/mc1206f105z500ct/condensatore-mlcc-y5v-1uf-50v/dp/1759455) | 0.06 | 1 | 0.63
100nF | MC1206B104K500CT | 1206 | capacitor | 1759361 (http://it.farnell.com/multicomp/mc1206b104k500ct/condensatore-mlcc-x7r-100nf-50v/dp/1759361) | 0.04 | 1 | 0.35
- | 61304011021 | 2.54 mm | pin header | 2356192 (http://it.farnell.com/wurth-elektronik/61304011021/header-2-54mm-pin-tht-r-a-40way/dp/2356192) | 1.77 | 1 | 1.77
- | M20-9990246 | 2.54 mm | pin header | 1022247 (http://it.farnell.com/harwin/m20-9990246/header-diritta-2-54mm-1row-bifase/dp/1022247) | 0.07 | 1 | 0.65
 |  |  |  |  |  |  | Total cost
 |  |  |  |  |  |  | 7.27

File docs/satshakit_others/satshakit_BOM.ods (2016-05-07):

Value | Manufacturer Part No | Package | Description | FARNELL | Price € | Quantity | Min. Quantity Cost €
- | ATMEGA328P-AU | TQFP-32 | microcontroller | 1715486 (http://it.farnell.com/atmel/atmega328p-au/mcu-8bit-atmega-20mhz-tqfp-32/dp/1715486) | 2.78 | 1 | 2.78
16Mhz/18pF | MCRSD16000F183000RR | SMD 11.4 x 4.7 mm | crystal | 2395958 (http://it.farnell.com/multicomp/mcrsd16000f183000rr/crystal-16mhz-18pf-hc49-us-smd/dp/2395958) | 0.20 | 1 | 0.20
green | MCL-S250GC | 1206 | green led | 1581232 (http://it.farnell.com/multicomp/mcl-s250gc/led-smd-1206-verde/dp/1581232) | 0.12 | 1 | 0.60
yellow | MCL-S250YC | 1206 | yellow led | 1581231 (http://it.farnell.com/multicomp/mcl-s250yc/led-smd-1206-giallo/dp/1581231) | 0.05 | 1 | 0.26
- | B3SN-3112P | 6 x 6 x 3.1 mm | switch | 2076274 (http://it.farnell.com/omron-electronic-components/b3sn-3112p/switch-6x6x3-1mm-sealed-1-57n/dp/2076274) | 0.65 | 1 | 0.65
10K | ERJ8GEYJ103V | 1206 | resistor | 2057856 (http://it.farnell.com/panasonic-electronic-components/erj8geyj103v/resistore-1206-10k-5-0-25w/dp/2057856) | 0.03 | 1 | 0.26
499 | CRCW1206499RFKEA | 1206 | resistor | 1470020 (http://it.farnell.com/vishay-draloric/crcw1206499rfkea/resistor-1206-499r-1/dp/1470020) | 0.03 | 2 | 0.28
22pF | MC1206N220J500CT | 1206 | capacitor | 2320891 (http://it.farnell.com/multicomp/mc1206n220j500ct/condens-mlcc-c0g-np0-22pf-50v/dp/2320891) | 0.05 | 2 | 0.47
10uF | MC1206X106K250CT | 1206 | capacitor | 2112753 (http://it.farnell.com/multicomp/mc1206x106k250ct/condensatore-mlcc-x5r-10uf-25v/dp/2112753) | 0.15 | 1 | 0.15
1uF | MC1206F105Z500CT | 1206 | capacitor | 1759455 (http://it.farnell.com/multicomp/mc1206f105z500ct/condensatore-mlcc-y5v-1uf-50v/dp/1759455) | 0.06 | 1 | 0.63
100nF | MC1206B104K500CT | 1206 | capacitor | 1759361 (http://it.farnell.com/multicomp/mc1206b104k500ct/condensatore-mlcc-x7r-100nf-50v/dp/1759361) | 0.04 | 2 | 0.35
- | 61304011021 | 2.54 mm | pin header | 2356192 (http://it.farnell.com/wurth-elektronik/61304011021/header-2-54mm-pin-tht-r-a-40way/dp/2356192) | 1.77 | 1 | 1.77
- | M20-9990246 | 2.54 mm | pin header | 1022247 (http://it.farnell.com/harwin/m20-9990246/header-diritta-2-54mm-1row-bifase/dp/1022247) | 0.07 | 1 | 0.65
 |  |  |  |  |  |  | Total cost
 |  |  |  |  |  |  | 9.06

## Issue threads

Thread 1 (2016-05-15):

schematic file doesn't open in eagle

yogee1707, 2016-05-15:
This year I'm doing FAB Academy 2016. For my input devices assignment.
I'm using the Ubuntu 16.04 and I've using EAGLE 7.5.0 to open the .sch or .brd file. EAGLE shown.

while opening files with EAGLE I got the error as follows

**Loading /home/yogee/eagle/satshaKit/satshakit_cnc.brd ...

Error:

line 6, column 41: This is not an EAGLE file.**

and

**
Loading /home/yogee/eagle/satshaKit/satshakit_cnc.sch ...

Error:

line 6, column 41: This is not an EAGLE file.
**

Wondering why this is happening. Because as per my knowledge the all EAGLE files are backward compatible.

satshas, 2016-05-15:
Hello,
I have done the following:

1. tried to open all the Eagle files in the repo using Ubuntu 16.04 x64 (fresh virtual box install) with Eagle 7.5.0, and is possible to **open all of them with no problems**
2. tried to open again all the files using Mac OSX with Eagle 7.5.0, **everything ok**
3. tried to open again all the files using Windows 10 with Eagle 7.5.0, **everything ok**

Maybe the issue is elsewhere?
How do you downloaded the files?
Could you try to do so using in terminal -> git clone https://github.com/satshas/satshakit.git

Let me know if you solve the problem.

Thanks.

Daniele.

satshas, 2016-05-17:
Ok, the problem is actually that you downloaded directly the sch/brd form the link of the repo. There you have to right click and download as. Otherwise you get something changed by the browser.

I have updated the repo with this instruction in each download section, therefore I am closing this issue.

Please open another one if you still have problems.

yogee1707, 2016-05-21:
Have cloned the repo and able to open file without any problem. Thank You.

Closed 2016-05-17.

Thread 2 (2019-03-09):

Is it possible to swap the crystal for a resonator?

andrewsleigh, 2019-03-09:
Hi Daniele, I'm trying to make a modified version of this board, mostly just with different headers to make programming easier. But I was also thinking of swapping out the crystal (and capacitors) for a resonator. Is there any reason why you used this as the clock source over a resonator? Would a resonator still keep the same level of Arduino compatibility? (I really like this aspect.)

satshas, 2019-03-10:
Hi Andrew,

first of all refer to the following repository: https://github.com/satshakit/satshakit

This is one is outdated as you can read at the beginning of the README.

You can certainly swap the crystal for a resonator, the reason why I am using a crystal is about the precision of the clock.

Crystals are more accurate and stable in higher ranges of temperatures than resonator. Accurate clock means less problems/more stability in communication protocols, usage of software requiring precise frequencies,  readings and so on.  Also this is helpful in our environment where our boards are made with the CNC and soldered by hand, and where our project are prototypes, therefore requiring a stable and reliable electronics to count on.

The original objective of the satshakit was to be a flight controller of my drone, thus the usage of the crystal.

If your board does not have such mission critical purpose, and you are ok with lowering the clock stability then that's ok.

Daniele

Closed 2019-03-10.

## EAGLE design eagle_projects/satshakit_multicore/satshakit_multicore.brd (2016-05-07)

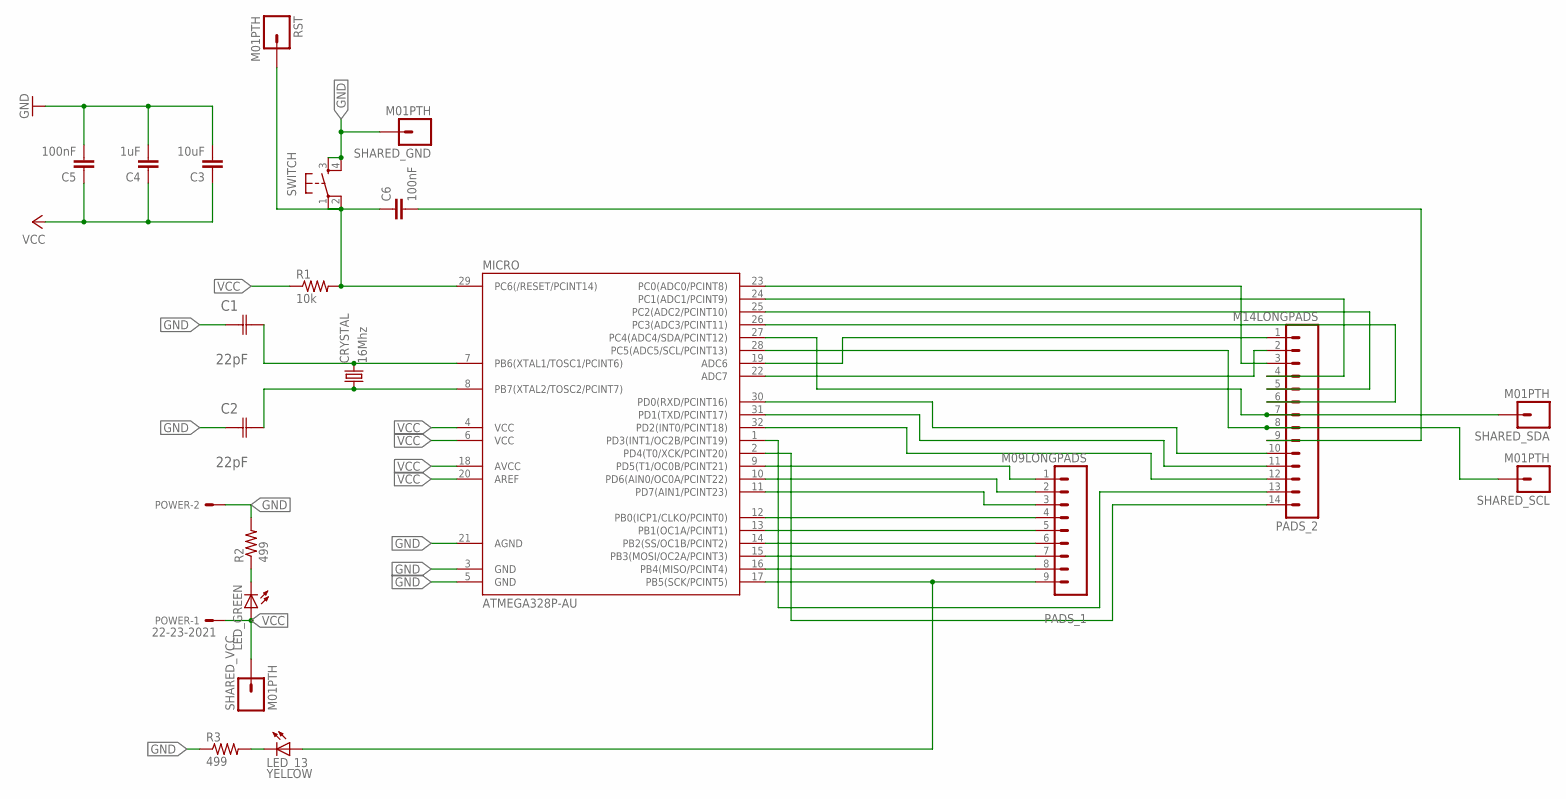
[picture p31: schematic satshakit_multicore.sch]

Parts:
C1, C2: 22pF; CAPC3216X178N
C3: 10uF; 1206
C4: 1uF; 1206
C5, C6: 100nF; 1206
CRYSTAL: 16Mhz; CSM-7X-DU
LED_13: YELLOW; 1206
LED_GREEN: LED1206; 1206
MICRO: ATMEGA328P-AU; TQFP32-08
PADS_1: M09LONGPADS; 1X09_LONGPADS
PADS_2: M14LONGPADS; 1X14-LONGPADS
POWER: 22-23-2021
R1: 10k; 1206
R2, R3: 499; 1206
RST: M01PTH; 1X01
SHARED_GND: M01PTH; 1X01
SHARED_SCL: M01PTH; 1X01
SHARED_SDA: M01PTH; 1X01
SHARED_VCC: M01PTH; 1X01
SWITCH: 6MM_SWITCH6MM_SWITCH; 6MM_SWITCH

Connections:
GND: C1.1 (C1), C2.1 (C1), C3.2, C4.2, C5.2, MICRO.3 (GND), MICRO.5 (GND), MICRO.21 (AGND), POWER.2, R2.2, R3.1, SHARED_GND.1, SWITCH.3 (S), SWITCH.4 (S1)
unnamed: MICRO.9 (PD5(T1/OC0B/PCINT21)), PADS_1.1
unnamed: C1.2 (C2), CRYSTAL.2, MICRO.7 (PB6(XTAL1/TOSC1/PCINT6))
unnamed: C6.2, PADS_2.9
unnamed: MICRO.10 (PD6(AIN0/OC0A/PCINT22)), PADS_1.2
unnamed: MICRO.11 (PD7(AIN1/PCINT23)), PADS_1.3
unnamed: MICRO.12 (PB0(ICP1/CLKO/PCINT0)), PADS_1.4
unnamed: MICRO.13 (PB1(OC1A/PCINT1)), PADS_1.5
unnamed: MICRO.14 (PB2(SS/OC1B/PCINT2)), PADS_1.6
unnamed: C2.2 (C2), CRYSTAL.1, MICRO.8 (PB7(XTAL2/TOSC2/PCINT7))
unnamed: MICRO.15 (PB3(MOSI/OC2A/PCINT3)), PADS_1.7
unnamed: MICRO.16 (PB4(MISO/PCINT4)), PADS_1.8
unnamed: LED_13.1 (A), MICRO.17 (PB5(SCK/PCINT5)), PADS_1.9
unnamed: MICRO.19 (ADC6), PADS_2.1
unnamed: MICRO.22 (ADC7), PADS_2.2
unnamed: MICRO.23 (PC0(ADC0/PCINT8)), PADS_2.3
unnamed: MICRO.24 (PC1(ADC1/PCINT9)), PADS_2.4
unnamed: MICRO.25 (PC2(ADC2/PCINT10)), PADS_2.5
unnamed: MICRO.26 (PC3(ADC3/PCINT11)), PADS_2.6
unnamed: MICRO.27 (PC4(ADC4/SDA/PCINT12)), PADS_2.7, SHARED_SDA.1
unnamed: MICRO.30 (PD0(RXD/PCINT16)), PADS_2.10
unnamed: MICRO.31 (PD1(TXD/PCINT17)), PADS_2.11
unnamed: MICRO.32 (PD2(INT0/PCINT18)), PADS_2.12
unnamed: MICRO.1 (PD3(INT1/OC2B/PCINT19)), PADS_2.13
unnamed: MICRO.2 (PD4(T0/XCK/PCINT20)), PADS_2.14
unnamed: MICRO.28 (PC5(ADC5/SCL/PCINT13)), PADS_2.8, SHARED_SCL.1
unnamed: LED_GREEN.2 (C), R2.1
unnamed: LED_13.2 (C), R3.2
unnamed: C6.1, MICRO.29 (PC6(/RESET/PCINT14)), R1.2, RST.1, SWITCH.1, SWITCH.2 (P1)
VCC: C3.1, C4.1, C5.1, LED_GREEN.1 (A), MICRO.4 (VCC), MICRO.6 (VCC), MICRO.18 (AVCC), MICRO.20 (AREF), POWER.1, R1.1, SHARED_VCC.1

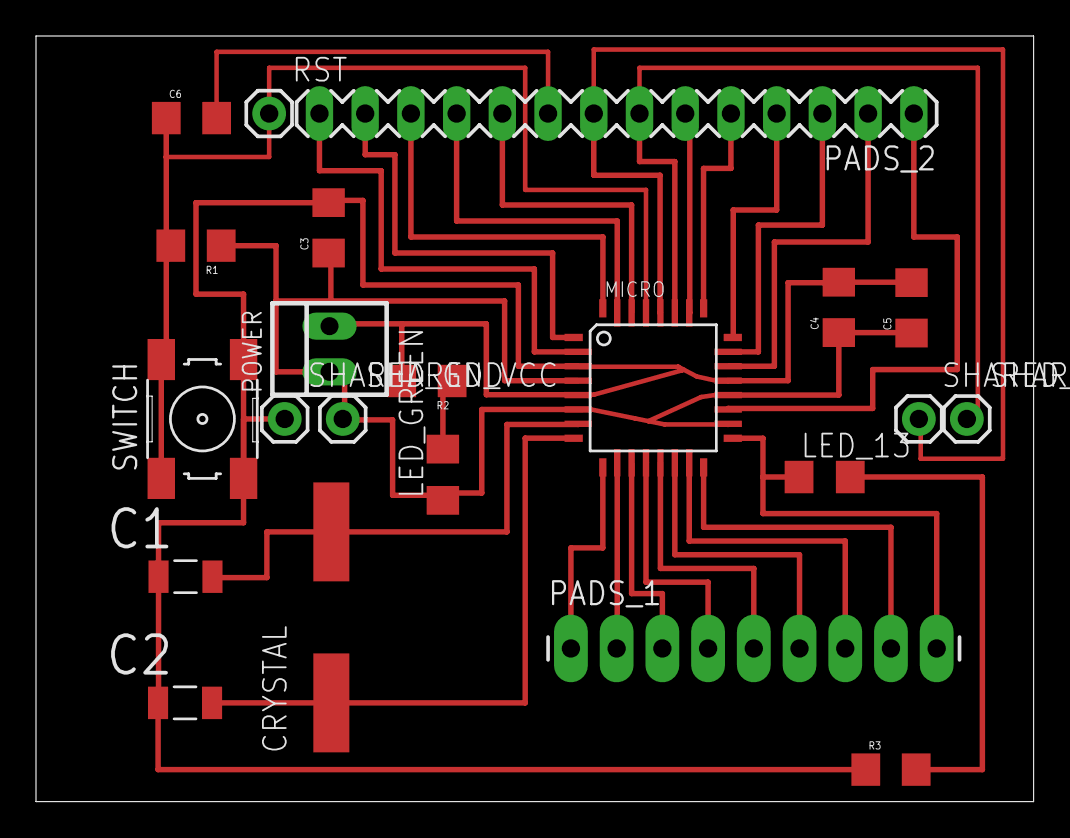
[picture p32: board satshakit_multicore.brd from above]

Board: 2 copper layers, 55.4 x 42.5 mm, 22 parts (0 on the bottom side), 30 nets.

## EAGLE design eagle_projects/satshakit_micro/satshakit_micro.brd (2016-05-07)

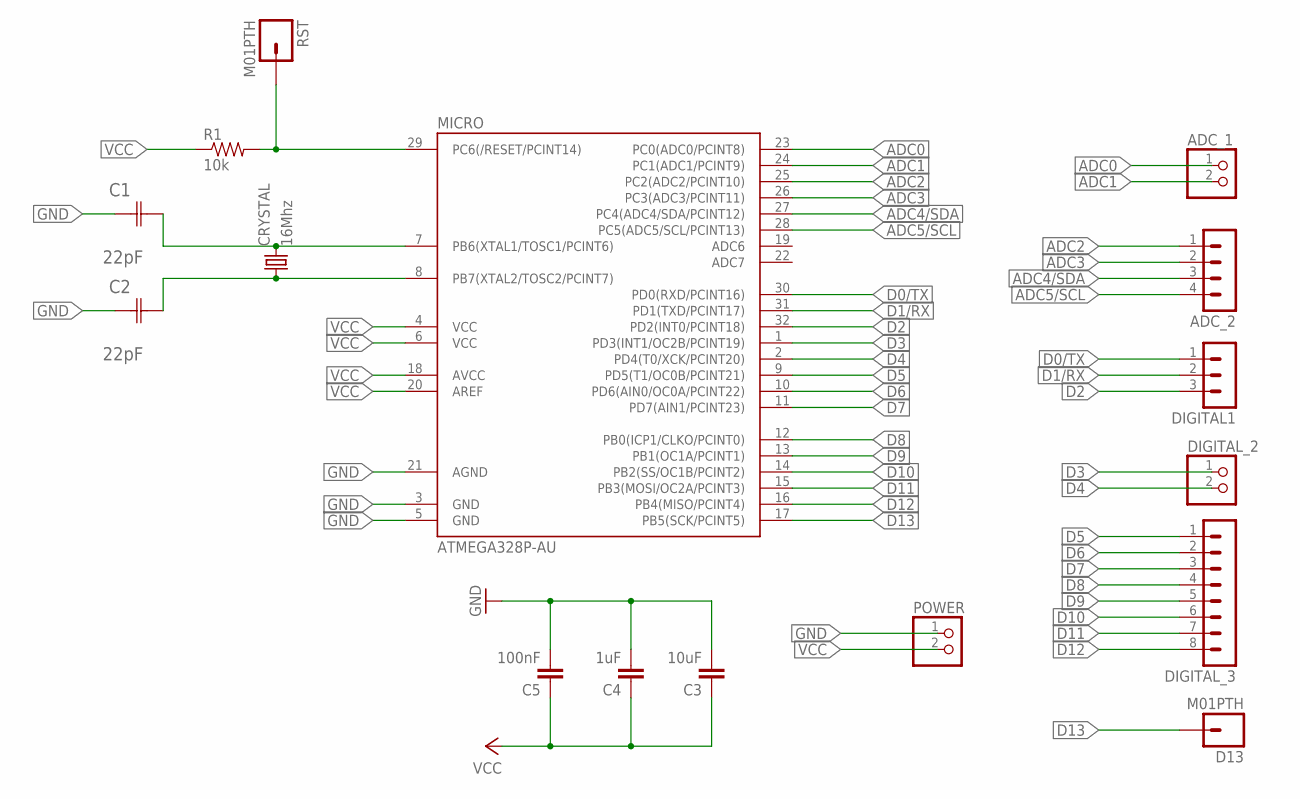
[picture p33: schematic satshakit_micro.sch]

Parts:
ADC_1: PINHD-1X2; 1X02
ADC_2: MA04-1
C1, C2: 22pF; CAPC3216X178N
C3: 10uF; 1206
C4: 1uF; 1206
C5: 100nF; 1206
CRYSTAL: 16Mhz; CSM-7X-DU
D13: M01PTH; 1X01
DIGITAL1: MA03-1
DIGITAL_2: PINHD-1X2; 1X02
DIGITAL_3: MA08-1
MICRO: ATMEGA328P-AU; TQFP32-08
POWER: PINHD-1X2; 1X02
R1: 10k; 1206
RST: M01PTH; 1X01

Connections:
ADC0: ADC_1.1, MICRO.23 (PC0(ADC0/PCINT8))
ADC1: ADC_1.2, MICRO.24 (PC1(ADC1/PCINT9))
ADC2: ADC_2.1, MICRO.25 (PC2(ADC2/PCINT10))
ADC3: ADC_2.2, MICRO.26 (PC3(ADC3/PCINT11))
ADC4/SDA: ADC_2.3, MICRO.27 (PC4(ADC4/SDA/PCINT12))
ADC5/SCL: ADC_2.4, MICRO.28 (PC5(ADC5/SCL/PCINT13))
D0/TX: DIGITAL1.1, MICRO.30 (PD0(RXD/PCINT16))
D1/RX: DIGITAL1.2, MICRO.31 (PD1(TXD/PCINT17))
D2: DIGITAL1.3, MICRO.32 (PD2(INT0/PCINT18))
D3: DIGITAL_2.1, MICRO.1 (PD3(INT1/OC2B/PCINT19))
D4: DIGITAL_2.2, MICRO.2 (PD4(T0/XCK/PCINT20))
D5: DIGITAL_3.1, MICRO.9 (PD5(T1/OC0B/PCINT21))
D6: DIGITAL_3.2, MICRO.10 (PD6(AIN0/OC0A/PCINT22))
D7: DIGITAL_3.3, MICRO.11 (PD7(AIN1/PCINT23))
D8: DIGITAL_3.4, MICRO.12 (PB0(ICP1/CLKO/PCINT0))
D9: DIGITAL_3.5, MICRO.13 (PB1(OC1A/PCINT1))
D10: DIGITAL_3.6, MICRO.14 (PB2(SS/OC1B/PCINT2))
D11: DIGITAL_3.7, MICRO.15 (PB3(MOSI/OC2A/PCINT3))
D12: DIGITAL_3.8, MICRO.16 (PB4(MISO/PCINT4))
D13: D13.1, MICRO.17 (PB5(SCK/PCINT5))
GND: C1.1 (C1), C2.1 (C1), C3.2, C4.2, C5.2, MICRO.3 (GND), MICRO.5 (GND), MICRO.21 (AGND), POWER.1
unnamed: C1.2 (C2), CRYSTAL.2, MICRO.7 (PB6(XTAL1/TOSC1/PCINT6))
unnamed: MICRO.29 (PC6(/RESET/PCINT14)), R1.2, RST.1
unnamed: C2.2 (C2), CRYSTAL.1, MICRO.8 (PB7(XTAL2/TOSC2/PCINT7))
VCC: C3.1, C4.1, C5.1, MICRO.4 (VCC), MICRO.6 (VCC), MICRO.18 (AVCC), MICRO.20 (AREF), POWER.2, R1.1

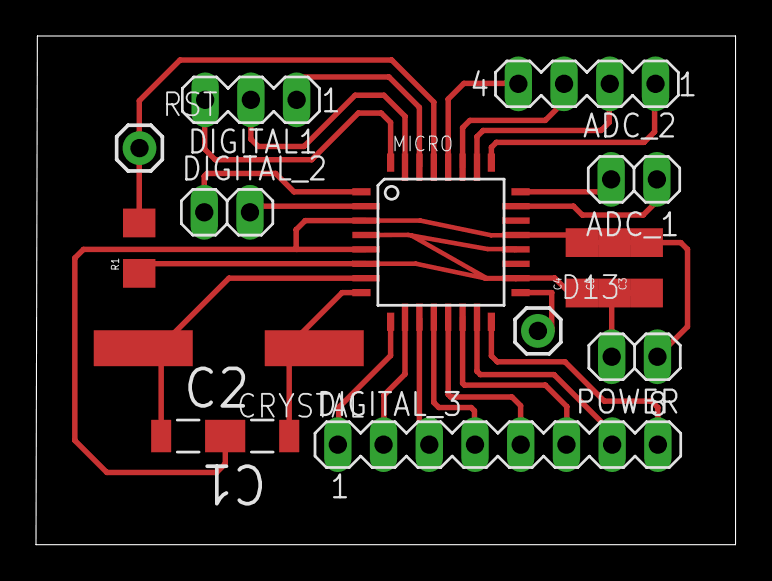
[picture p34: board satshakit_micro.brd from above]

Board: 2 copper layers, 38.9 x 28.3 mm, 16 parts (0 on the bottom side), 25 nets.

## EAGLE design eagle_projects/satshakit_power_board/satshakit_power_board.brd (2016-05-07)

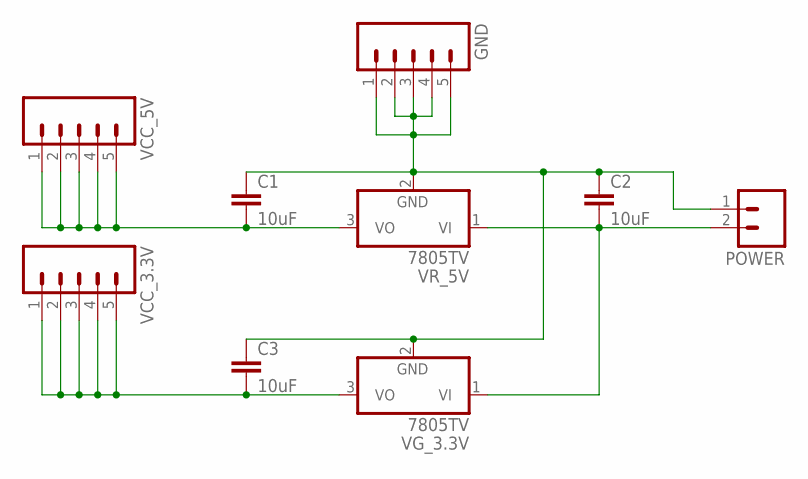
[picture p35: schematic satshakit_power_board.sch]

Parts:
C1, C2, C3: 10uF; 1206
GND: M05PTH_LONGPADS; 1X05_LONGPADS
POWER: M02; 1X02_LONGPADS
VCC_3.3V, VCC_5V: M05PTH_LONGPADS; 1X05_LONGPADS
VG_3.3V: 7805TV; TO220V
VR_5V: 7805TV; TO220V

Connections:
unnamed: C3.2, VCC_3.3V.1, VCC_3.3V.2, VCC_3.3V.3, VCC_3.3V.4, VCC_3.3V.5, VG_3.3V.3 (VO)
unnamed: C1.2, VCC_5V.1, VCC_5V.2, VCC_5V.3, VCC_5V.4, VCC_5V.5, VR_5V.3 (VO)
unnamed: C2.2, POWER.2, VG_3.3V.1 (VI), VR_5V.1 (VI)
unnamed: C1.1, C2.1, C3.1, GND.1, GND.2, GND.3, GND.4, GND.5, POWER.1, VG_3.3V.2 (GND), VR_5V.2 (GND)

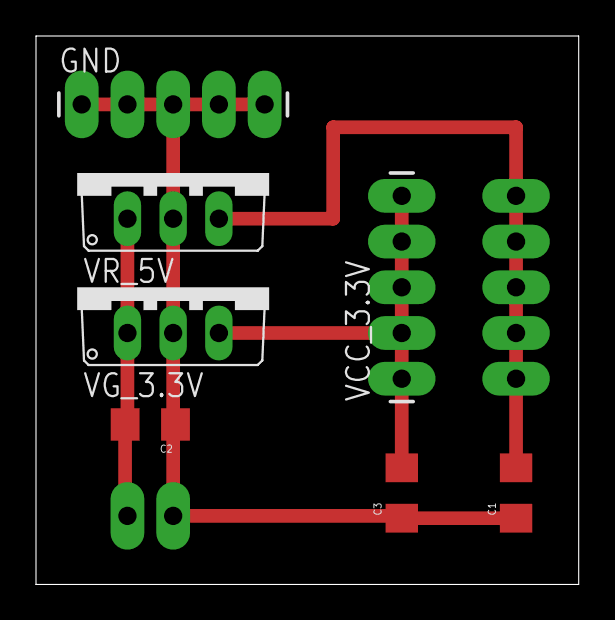
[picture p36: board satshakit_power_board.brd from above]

Board: 2 copper layers, 30.2 x 30.5 mm, 9 parts (1 on the bottom side), 4 nets.

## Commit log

2015-04-14 first satshakit commit
    [satshakit.brd, satshakit.sch, satshakit_BOM.ods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]
2015-04-19 v0.2 programming from FTDI cable
    [satshakit.brd, satshakit.sch, satshakit_BOM.ods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]
2015-04-20 fixed a little error on the board
    [satshakit.brd]
2015-04-21 minor fixes
    [satshakit.brd, satshakit.sch]
2015-04-27 added led matrix video
2015-05-06 added satshakit modular and power board
    [satshakit.brd, satshakit.sch, satshakit_modular.brd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]
2016-05-07 added satshakit micro and cnc versions, reoganized the readme file
    [satshakit.brd, satshakit.sch, satshakit_BOM.ods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]
2016-05-07 readme fixes
    [satshakit_multicore.brd, satshakit_multicore.sch]

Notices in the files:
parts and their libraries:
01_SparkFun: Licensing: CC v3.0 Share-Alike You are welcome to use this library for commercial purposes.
